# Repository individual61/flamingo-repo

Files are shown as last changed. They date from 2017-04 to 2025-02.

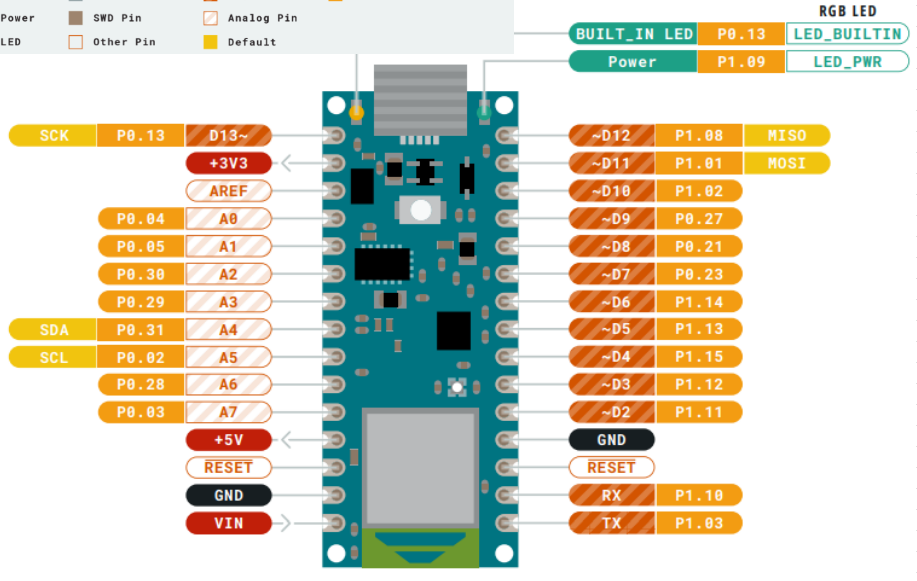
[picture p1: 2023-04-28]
Boards/Nano 33 BLE Flamingo/Flamingo Nano 33 BLE Rev 2/Arduino Nano 33 BLE Pinout.png

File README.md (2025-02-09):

FLAMINGO!

My festival buddy.My fave programs are the damped harmonic oscillator, the bouncing ball, and green fire. 

First iteration was a perfboard mess, second was a custom PCBA I designed and assembled. Currently runs off a small, flat USB power bank.



930DD853-4906-4F26-BFC8-F6EFBABEAD89

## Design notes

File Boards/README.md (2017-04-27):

This directory contains the board files.

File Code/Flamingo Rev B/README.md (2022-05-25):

Derived from the original version of Flamingo as presented at LiB 2015, then updated in 2017.

Runs on original, through-hole Flamingo hardware.

Hardware:

- Adafruit Pro Trinket 5 V
- Battery Backpack
- ADXL345/GY-291
- Adafruit APA102C pins.
- Qty 2 buttons

Setup guide, because I always forget. 

***Connections

I connect an Adafruit FTDI Fried, or CP2104 (discontinued) to the FTDI header of the Pro Trinket. I forget why I preferred this but I think it's better than uploading via USB. I USB might require unplugging and re-plugging but I'm not sure. 

I use a sparse APA102C strip for testing, at least initially. Not sure if my USB port can handle the current draw. I also have my power supply to power the light strip directly.

The grounds in this setup are linked at the light strip itself, which means that as long as the APA102C ground connects to USB ground on the Pro Trinket, they are linked. I'm pretty sure this is the case. 

WHen the light strip is powered this way, the Arduino is always powered on. 

Starting the serial monitor resets the Arduino.

***

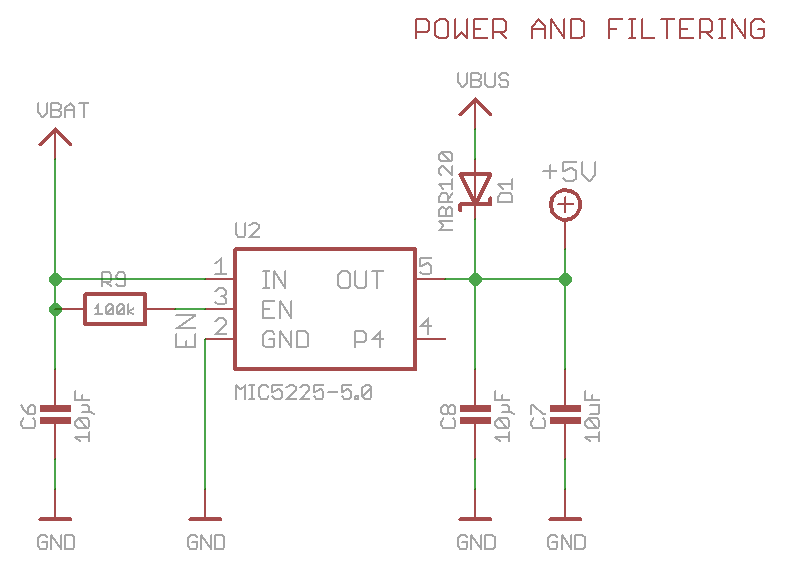
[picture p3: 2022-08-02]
Boards/Bike Flamingo IB-5V-USB/Bike Flamingo IB-5V-USB Rev 2/Images/ItsyBitsyPower.png

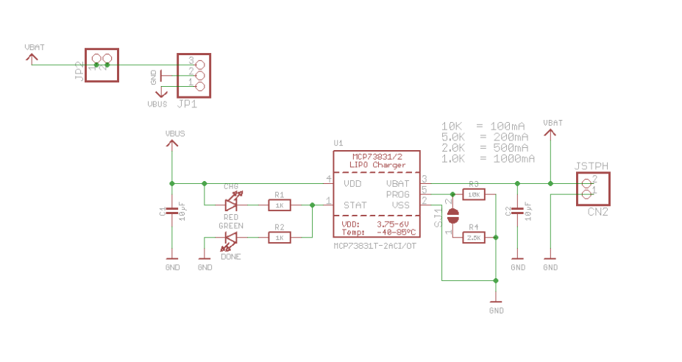
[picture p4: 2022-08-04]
Boards/Bike Flamingo IB-5V-USB/Bike Flamingo IB-5V-USB Rev 2/Images/Battery Backpack power.png

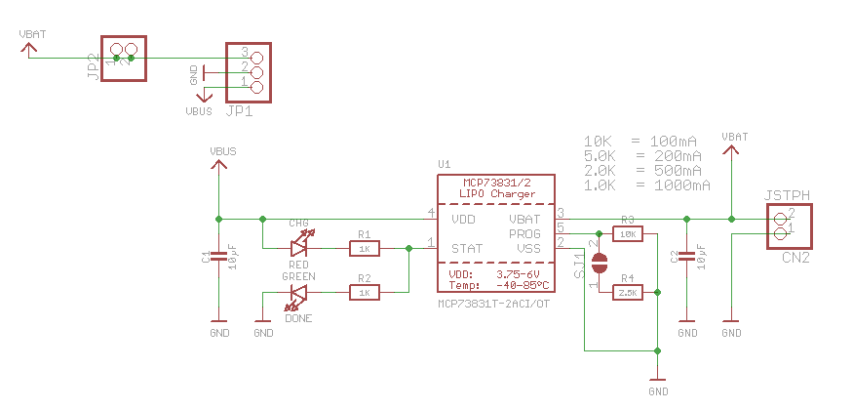
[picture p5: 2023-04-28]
Boards/Nano 33 BLE Flamingo/Flamingo Nano 33 BLE Rev 2/Adafruit Battery Backpack.png

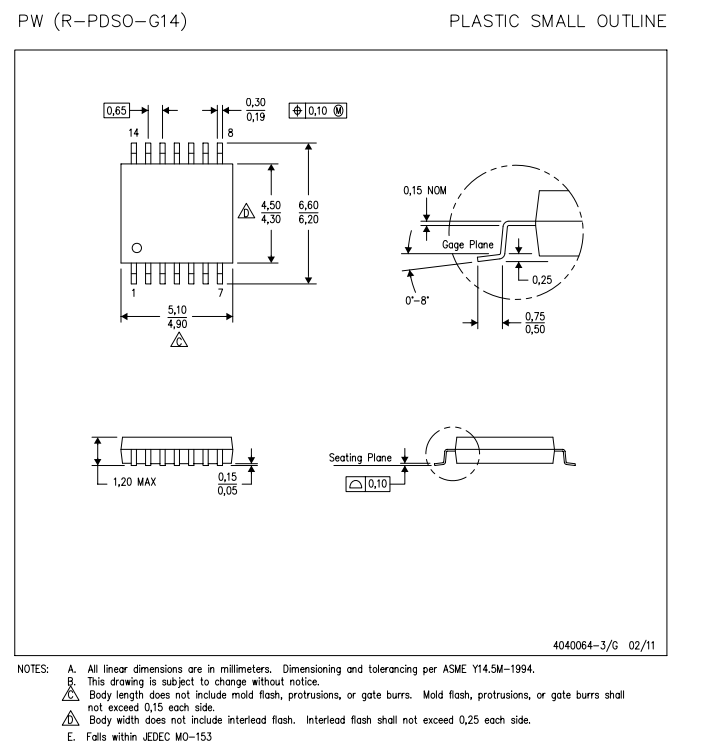
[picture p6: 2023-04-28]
Boards/Nano 33 BLE Flamingo/Flamingo Nano 33 BLE Rev 2/TSSOP 4.4 Package.png

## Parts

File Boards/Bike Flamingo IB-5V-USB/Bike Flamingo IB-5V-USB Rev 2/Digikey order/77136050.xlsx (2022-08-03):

Index | Quantity | Part Number | Manufacturer Part Number | Description | Customer Reference | Backorder | Unit Price | Extended Price
1 | 5 | 515PB-ND | 40-3979-00 | SWITCH PUSHBUTTON SPST 2A 14V |  | 0 | 2.69 | $13.45
2 | 20 | 455-1719-ND | S2B-PH-K-S(LF)(SN) | CONN HEADER R/A 2POS 2MM |  | 0 | 0.134 | $0.00
3 | 100 | CR0603-FX-3300ELFCT-ND | CR0603-FX-3300ELF | RES SMD 330 OHM 1% 1/10W 0603 |  | 0 | 0.0068 | $0.68
4 | 10 | A98335-ND | 282834-4 | TERM BLK 4P SIDE ENT 2.54MM PCB |  | 0 | 2.515 | $25.15
5 | 100 | CR0603-FX-4701ELFCT-ND | CR0603-FX-4701ELF | RES SMD 4.7K OHM 1% 1/10W 0603 |  | 0 | 0.0065 | $0.65
6 | 6 | 478-12972-1-ND | TPSF107M016R0200 | CAP TANT 100UF 20% 16V 2312 |  | 0 | 1.85 | $11.10
 |  |  |  |  |  |  | Subtotal | $51.03

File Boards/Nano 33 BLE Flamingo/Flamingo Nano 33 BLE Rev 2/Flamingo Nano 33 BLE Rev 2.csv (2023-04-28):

Source: | D:\Google Drive 6TB\Projects\Flamingo\flaming-repo\Boards\Nano 33 BLE Flamingo\Flamingo Nano 33 BLE Rev 2\Flamingo Nano 33 BLE Rev 2.kicad_sch
Date: | 4/26/2023 11:23:23 AM
Tool: | Eeschema 7.0.2
Generator: | D:\Program Files 6TB\KiCAD\7.0\bin\scripting\plugins/bom_csv_grouped_by_value_with_fp.py
Component Count: | 11
Ref | Qnty | Value | Cmp name | Footprint | Description | Vendor | DNP
C1 | 1 | 10 uF | C_Small_vert | Capacitor_SMD:C_0805_2012Metric_Pad1.18x1.45mm_HandSolder | Unpolarized capacitor vertical
C2 | 1 | 100uF | CP1_Small_vert | MyCapacitors:Cap Tant 100uF 16V 2mm height F size Kyocera AVX TPSF107M016R0200 | Polarised capacitor vertical
J1 | 1 | Button Board Term | Screw_Terminal_01x04 TE 282834-4 | TerminalBlock_TE-Connectivity:TerminalBlock_TE_282834-4_1x04_P2.54mm_Horizontal | Generic screw terminal, single row, 01x04, script generated (kicad-library-utils/schlib/autogen/connector/)
J2 | 1 | APA102C | Screw_Terminal_01x04 TE 282834-4 | TerminalBlock_TE-Connectivity:TerminalBlock_TE_282834-4_1x04_P2.54mm_Horizontal | Generic screw terminal, single row, 01x04, script generated (kicad-library-utils/schlib/autogen/connector/)
R1, R2, R3 | 3 | 4.7k | R_vert | Resistor_SMD:R_0603_1608Metric_Pad0.98x0.95mm_HandSolder | Resistor Vertical
R4, R5 | 2 | 330 | R_horiz_1 | Resistor_SMD:R_0603_1608Metric_Pad0.98x0.95mm_HandSolder | Resistor Horizontal
U1 | 1 | SN74AHCT125QPWRQ1 | 74AHCT125_Quad_Buffer-Level_Shifter | Package_SO:TSSOP-14_4.4x5mm_P0.65mm
XA1 | 1 | Arduino_Nano_33_BLE_Socket | Arduino_Nano_33_BLE_Socket | PCM_arduino-library:Arduino_Nano_Every_Socket | Socket for Arduino Nano 33 BLE

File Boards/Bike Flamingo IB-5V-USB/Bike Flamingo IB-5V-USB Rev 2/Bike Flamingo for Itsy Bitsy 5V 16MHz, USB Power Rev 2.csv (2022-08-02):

Source: | G:\My Drive\Projects\Flamingo\flaming-repo\Boards\Bike Flamingo for Itsy Bitsy 5V 16MHz, USB Power\Bike Flamingo for Itsy Bitsy 5V 16MHz, USB Power Rev 1\Bike Flamingo for Itsy Bitsy 5V 16MHz, USB Power Rev 1.kicad_sch
Date: | 8/2/2022 11:48:54 AM
Tool: | Eeschema (6.0.7)
Generator: | C:\Program Files\KiCad\6.0\bin\scripting\plugins/bom_csv_grouped_by_value_with_fp.py
Component Count: | 10
Ref | Qnty | Value | Cmp name | Footprint | Description | Vendor
C1, | 1 | 100uF | CP1_Small_vert | Capacitor_Tantalum_SMD:CP_EIA-6032-28_Kemet-C_Pad2.25x2.35mm_HandSolder | Polarised capacitor vertical
J1, | 1 | Battery Connector | 01x02_Connector | Connector_JST:JST_PH_S2B-PH-K_1x02_P2.00mm_Horizontal | Generic connector, single row, 01x02
J2, J3, | 2 | Button Board Terminal | Screw_Terminal_01x04 | TerminalBlock_TE-Connectivity:TerminalBlock_TE_282834-4_1x04_P2.54mm_Horizontal | Generic screw terminal, single row, 01x04, script generated (kicad-library-utils/schlib/autogen/connector/)
R1, R2, R3, | 3 | 4.7k | R_vert | Resistor_SMD:R_0603_1608Metric_Pad0.98x0.95mm_HandSolder | Resistor Vertical
R4, R5, | 2 | 330 | R_horiz | Resistor_SMD:R_0603_1608Metric_Pad0.98x0.95mm_HandSolder | Resistor Horizontal
U1, | 1 | Adafruit_ItsyBitsy_5V_16MHz | Adafruit_ItsyBitsy_5V_16MHz | MyBoards:Adafruit Itsy Bitsy 5V 16 MHz

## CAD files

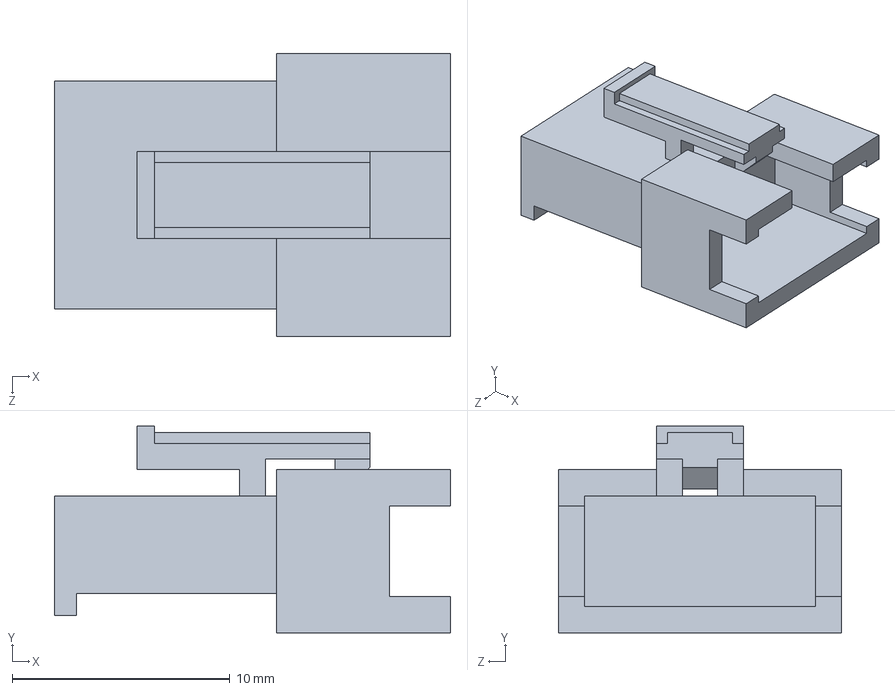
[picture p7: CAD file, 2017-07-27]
Boards/Flamingo PCBA/Components/JST SM Connectors/SMR-04V-B.STEP
18.2 x 9.50 x 13.0 mm

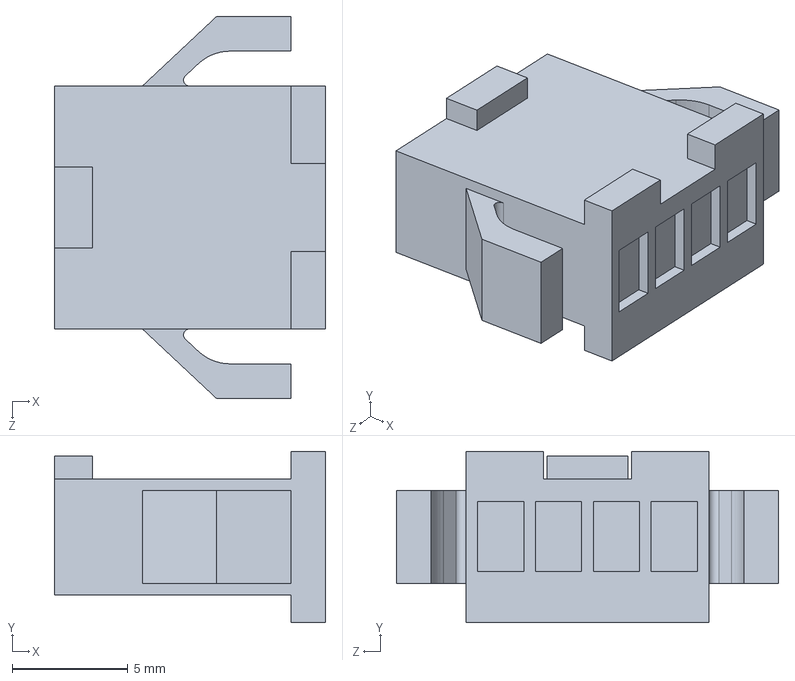
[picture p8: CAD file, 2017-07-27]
Boards/Flamingo PCBA/Components/JST SM Connectors/SMP-04V-BC.STEP
11.7 x 7.40 x 16.5 mm

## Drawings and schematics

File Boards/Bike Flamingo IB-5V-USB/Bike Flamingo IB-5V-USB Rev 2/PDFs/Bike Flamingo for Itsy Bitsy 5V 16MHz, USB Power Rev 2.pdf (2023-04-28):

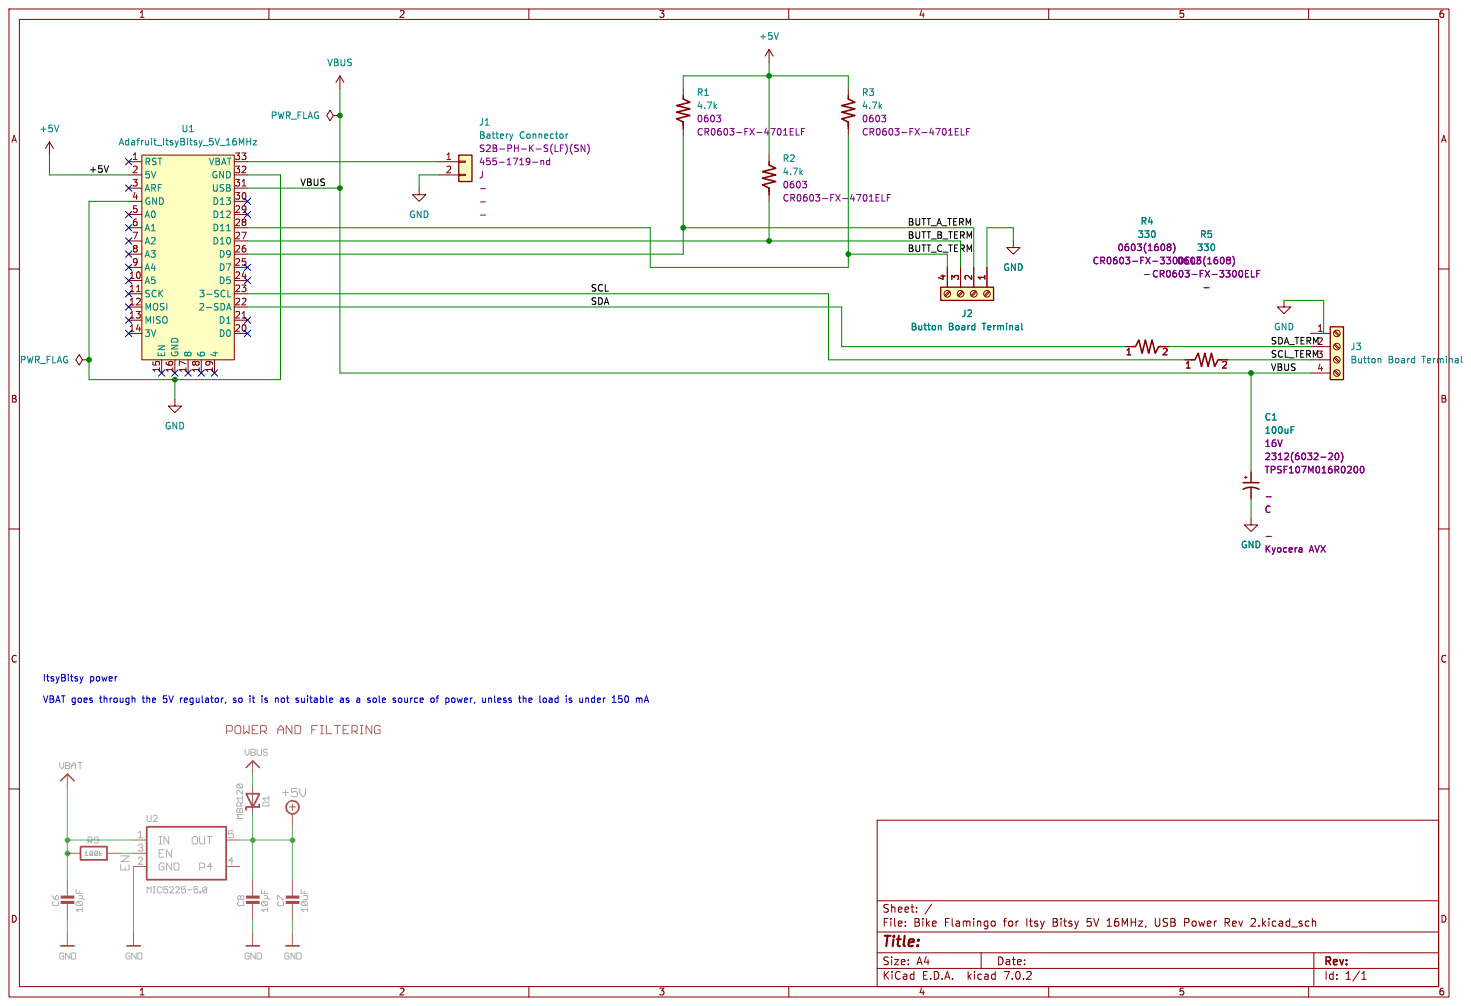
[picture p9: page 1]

J1Battery Connector S2B-PH-K-S(LF)(SN) 455-1719-nd

-Kyocera AVX GND GND

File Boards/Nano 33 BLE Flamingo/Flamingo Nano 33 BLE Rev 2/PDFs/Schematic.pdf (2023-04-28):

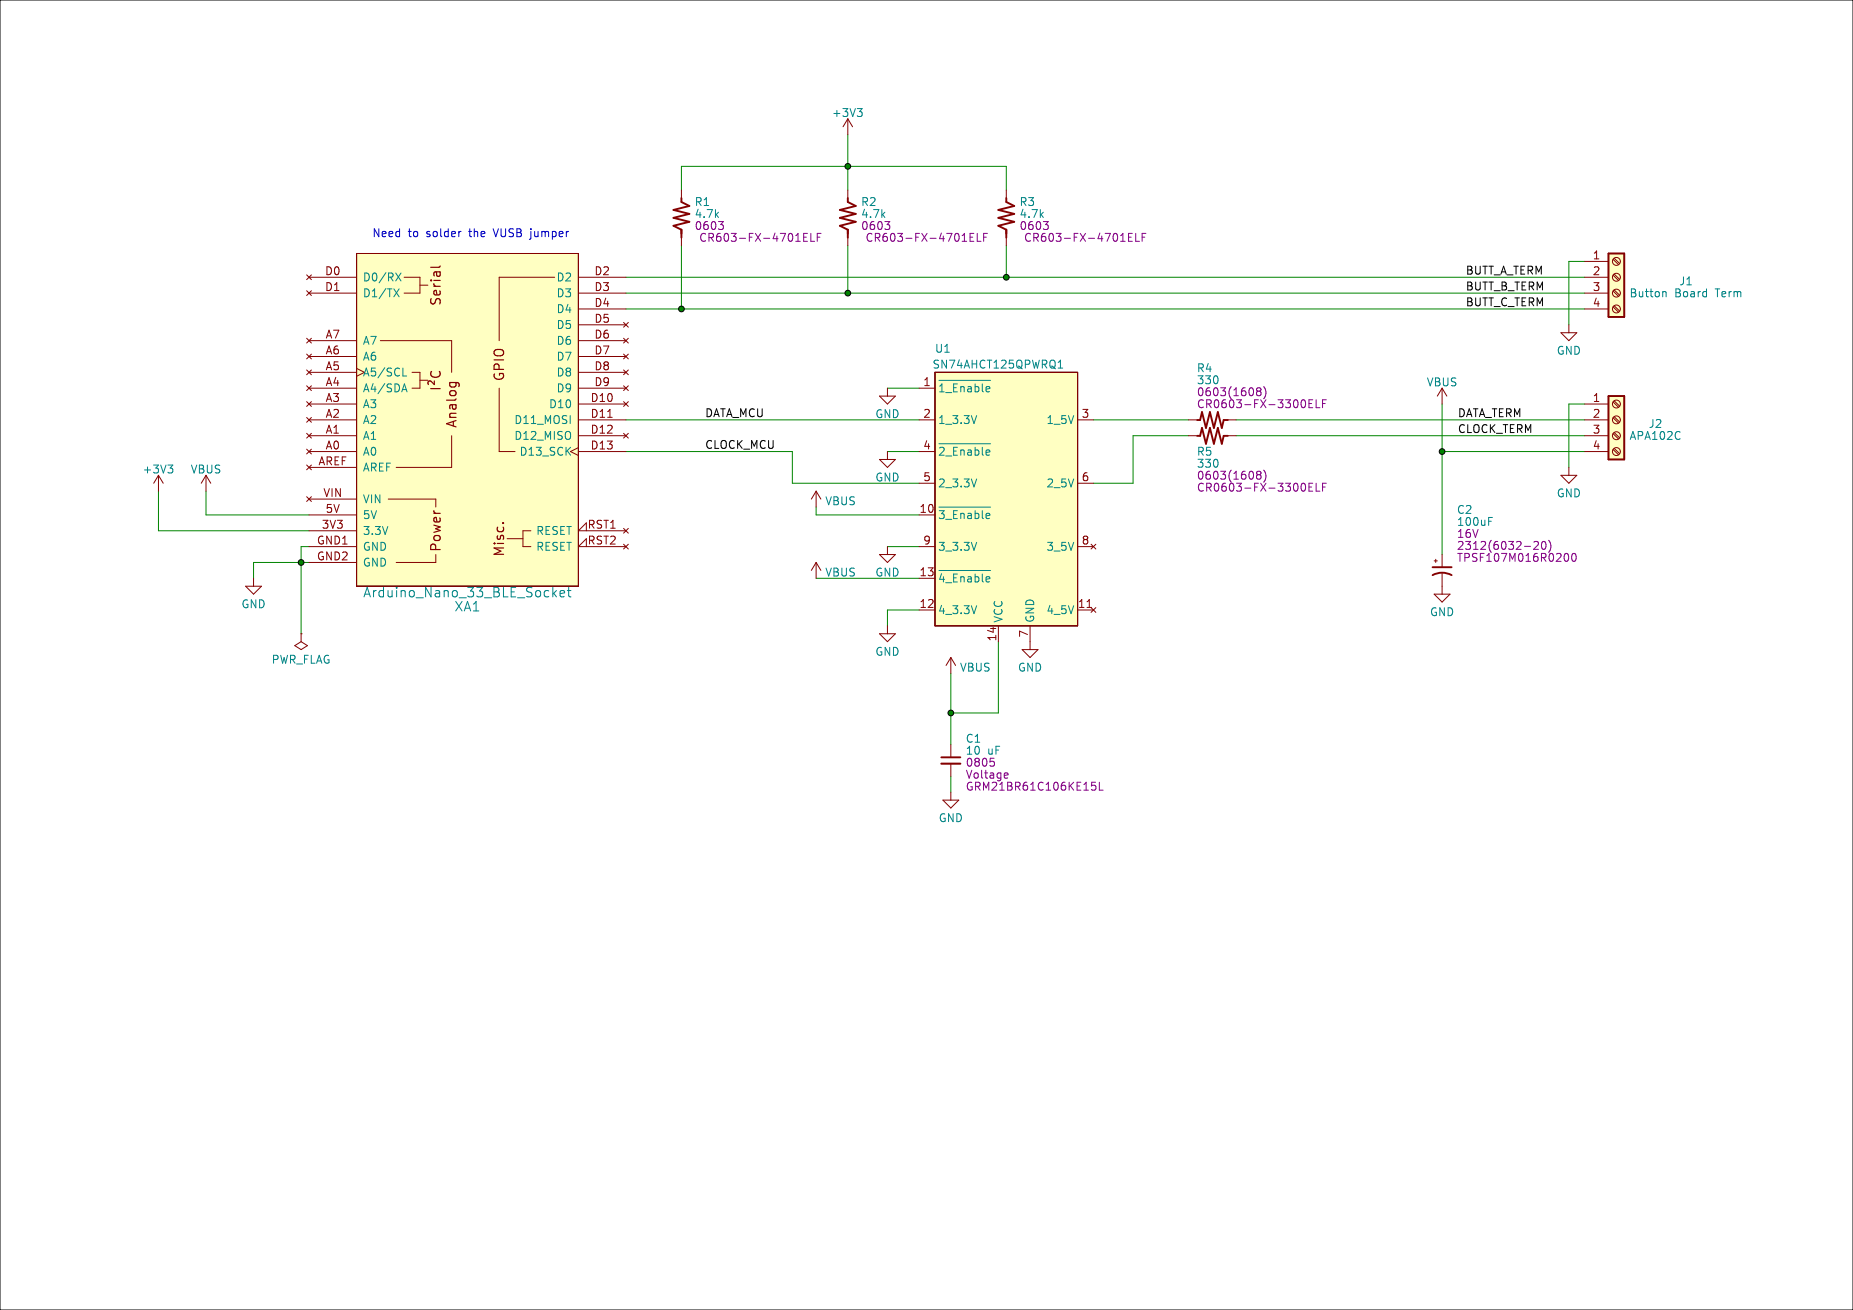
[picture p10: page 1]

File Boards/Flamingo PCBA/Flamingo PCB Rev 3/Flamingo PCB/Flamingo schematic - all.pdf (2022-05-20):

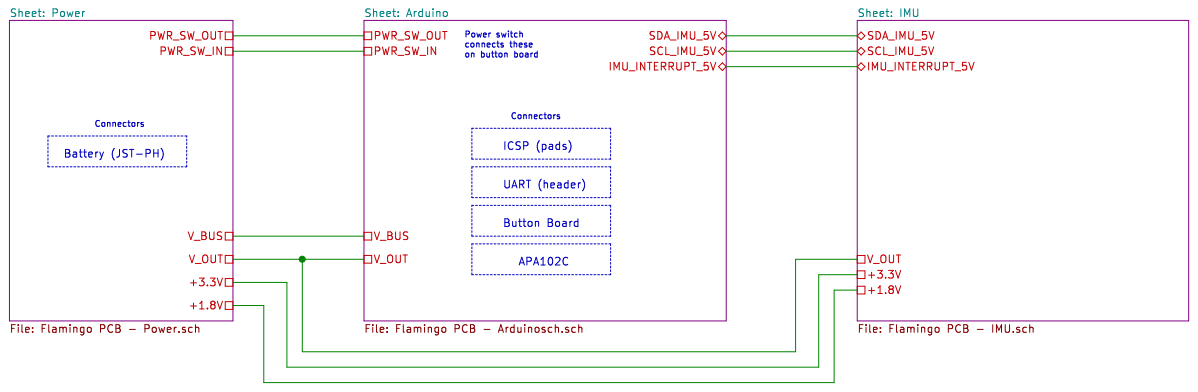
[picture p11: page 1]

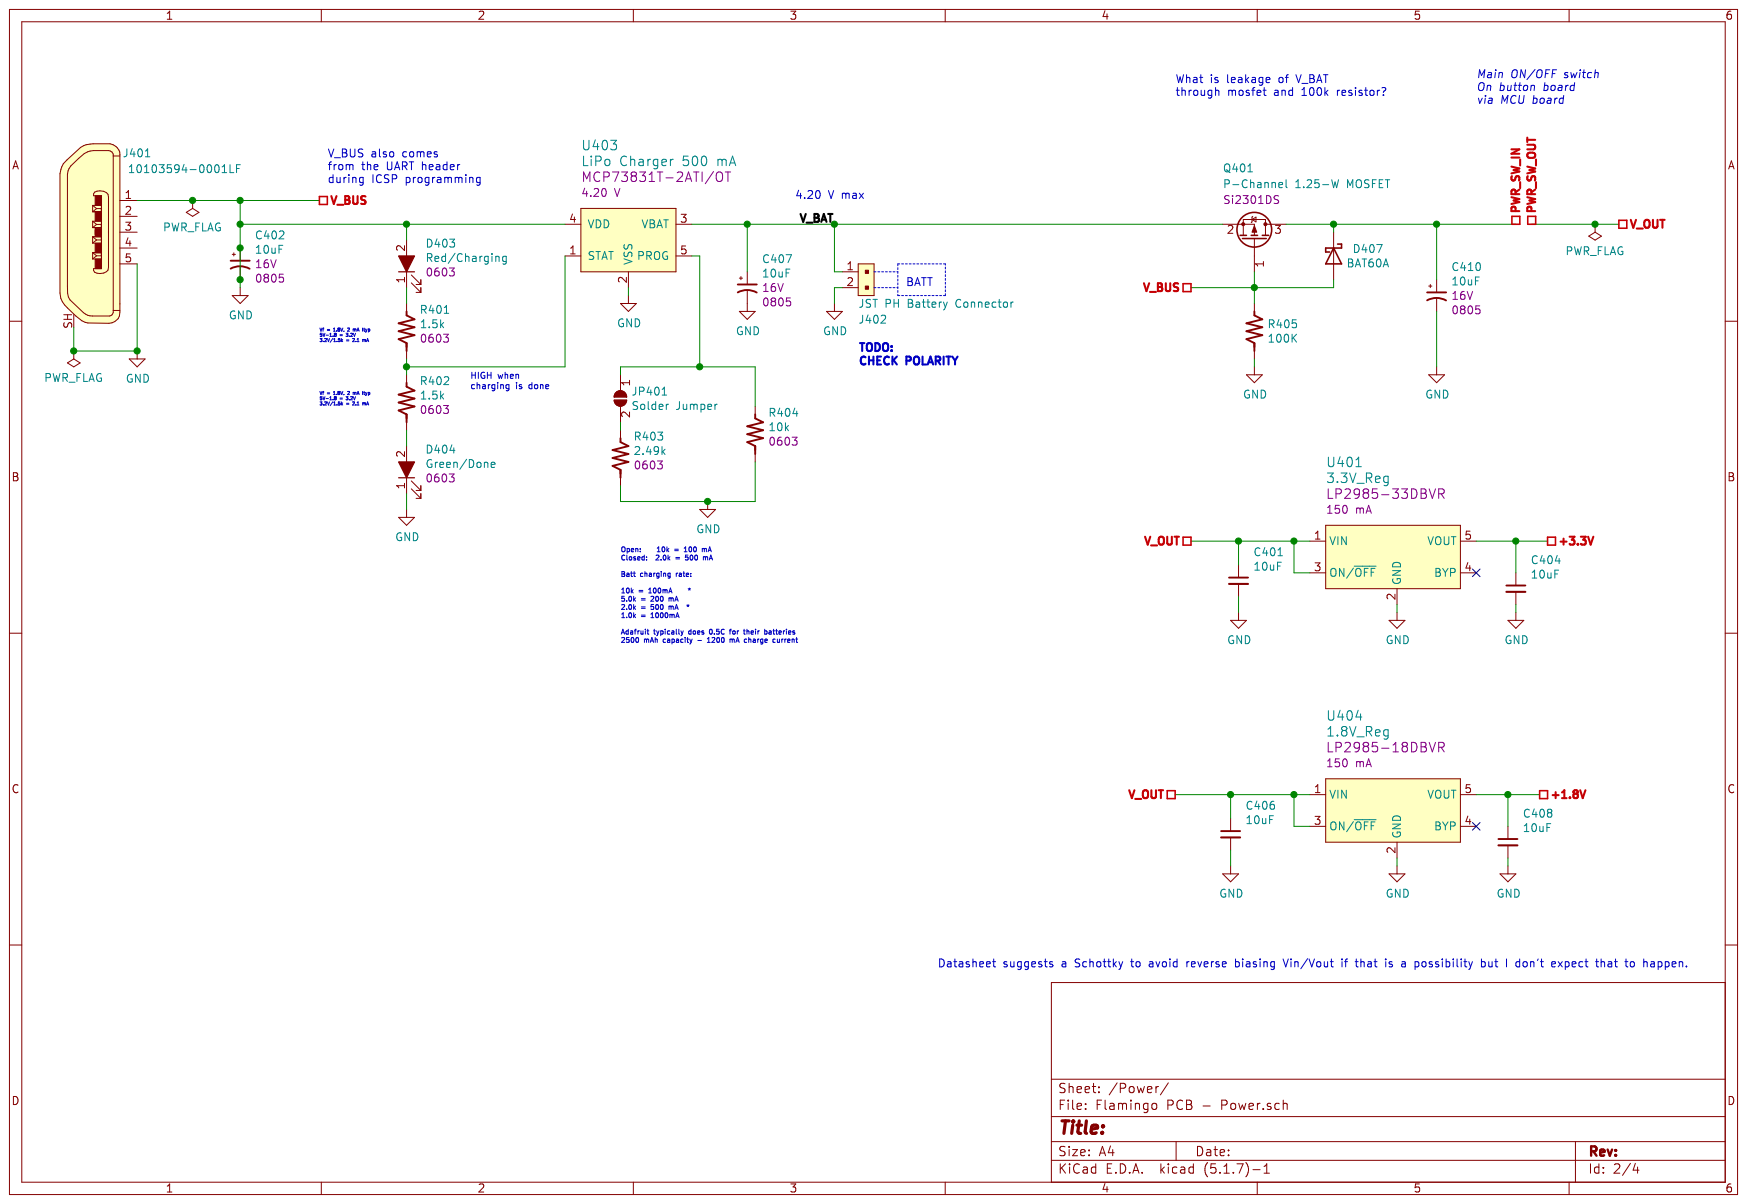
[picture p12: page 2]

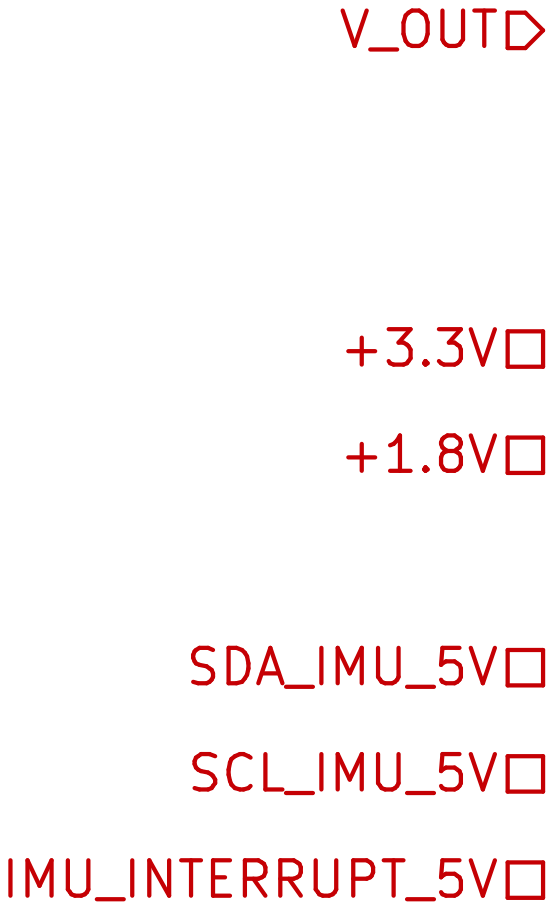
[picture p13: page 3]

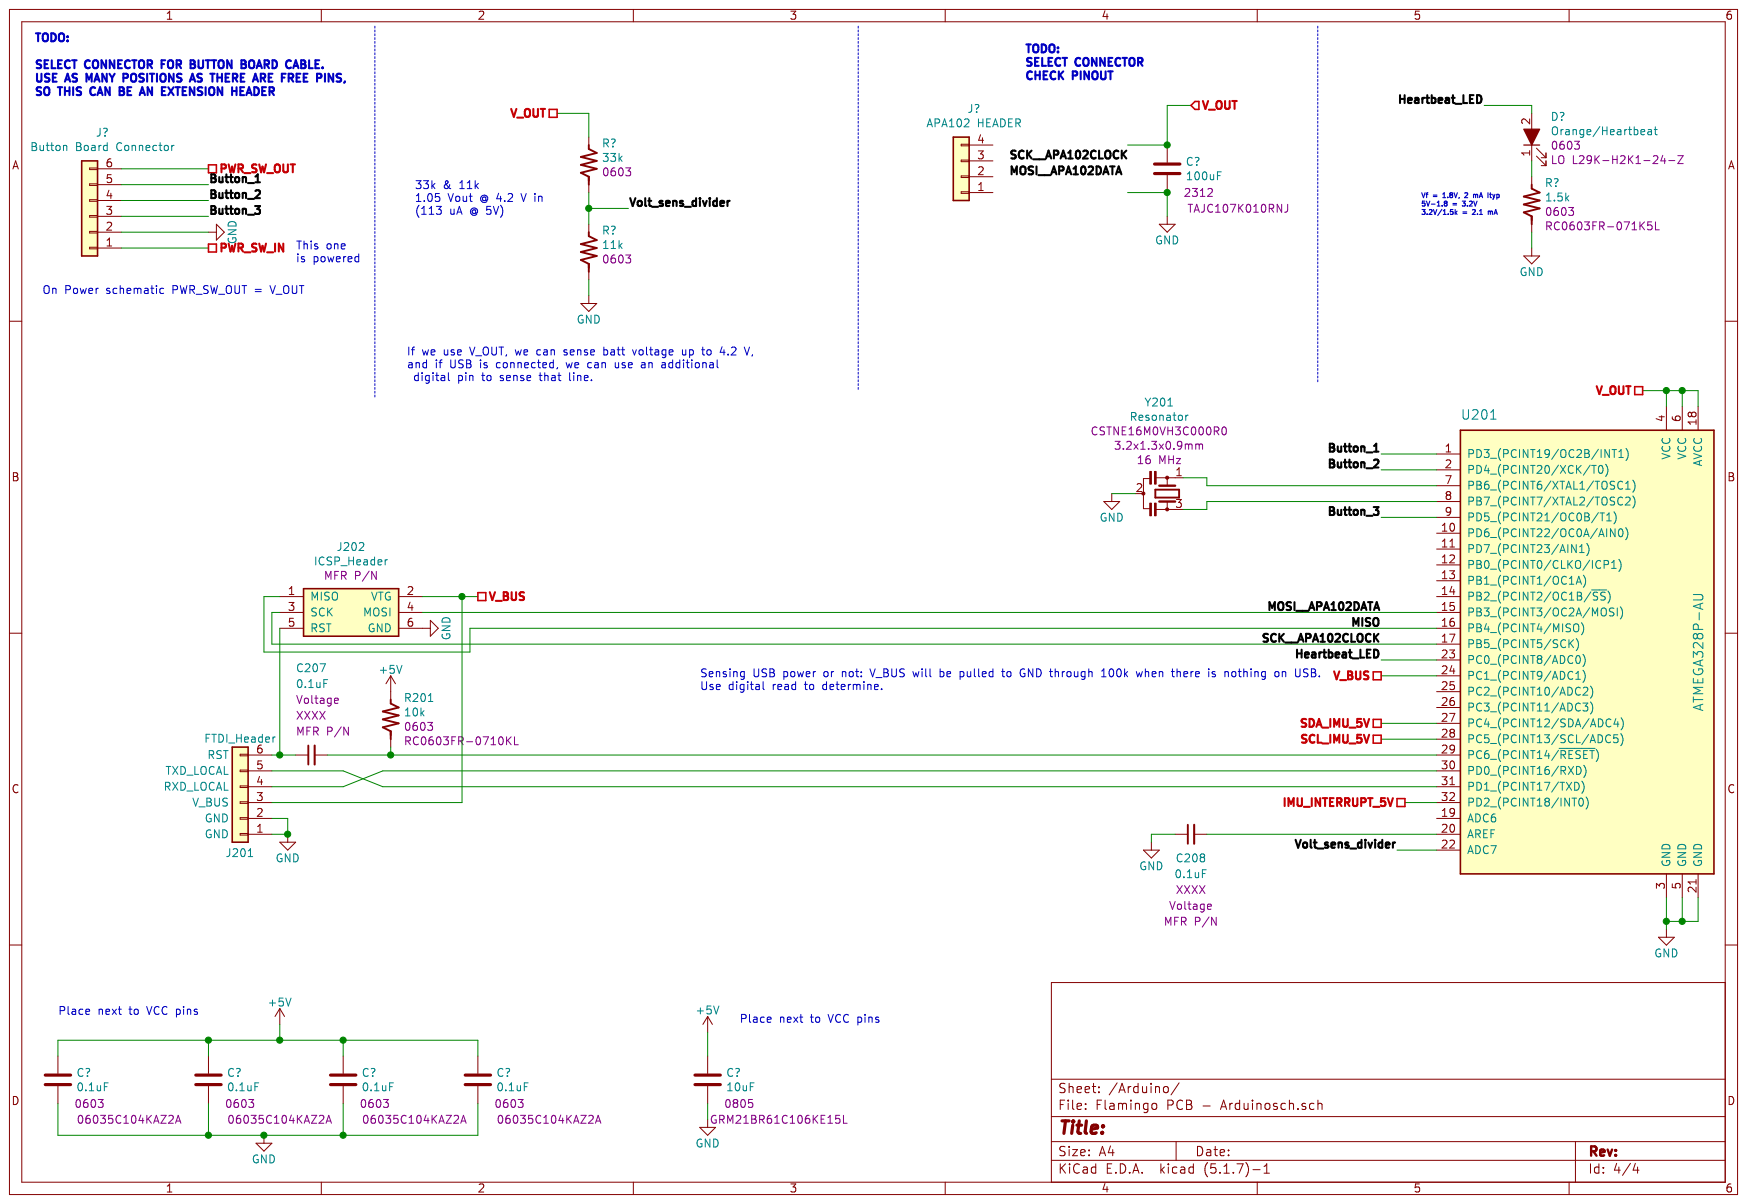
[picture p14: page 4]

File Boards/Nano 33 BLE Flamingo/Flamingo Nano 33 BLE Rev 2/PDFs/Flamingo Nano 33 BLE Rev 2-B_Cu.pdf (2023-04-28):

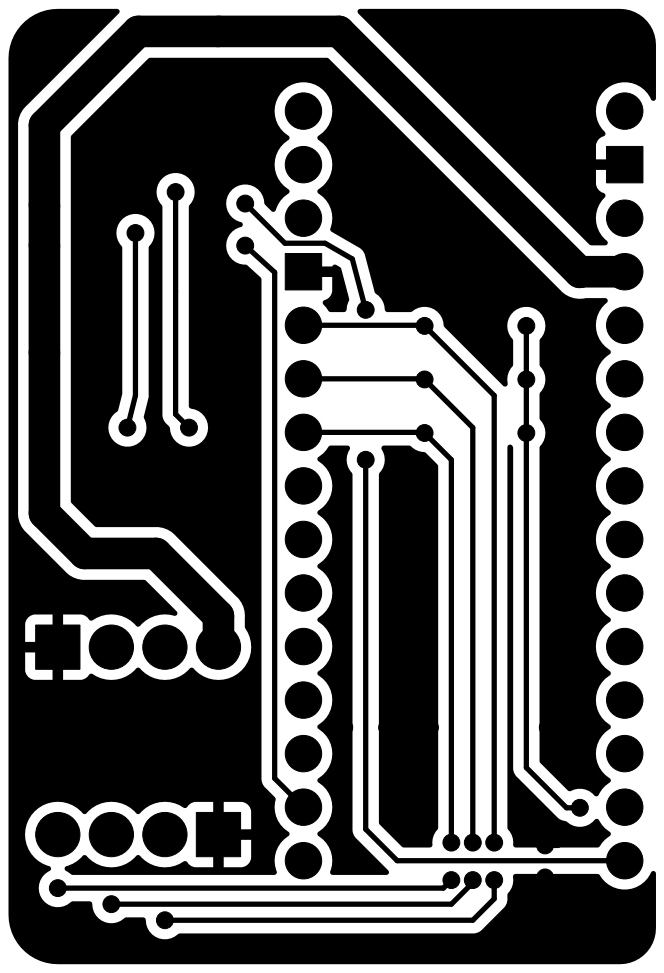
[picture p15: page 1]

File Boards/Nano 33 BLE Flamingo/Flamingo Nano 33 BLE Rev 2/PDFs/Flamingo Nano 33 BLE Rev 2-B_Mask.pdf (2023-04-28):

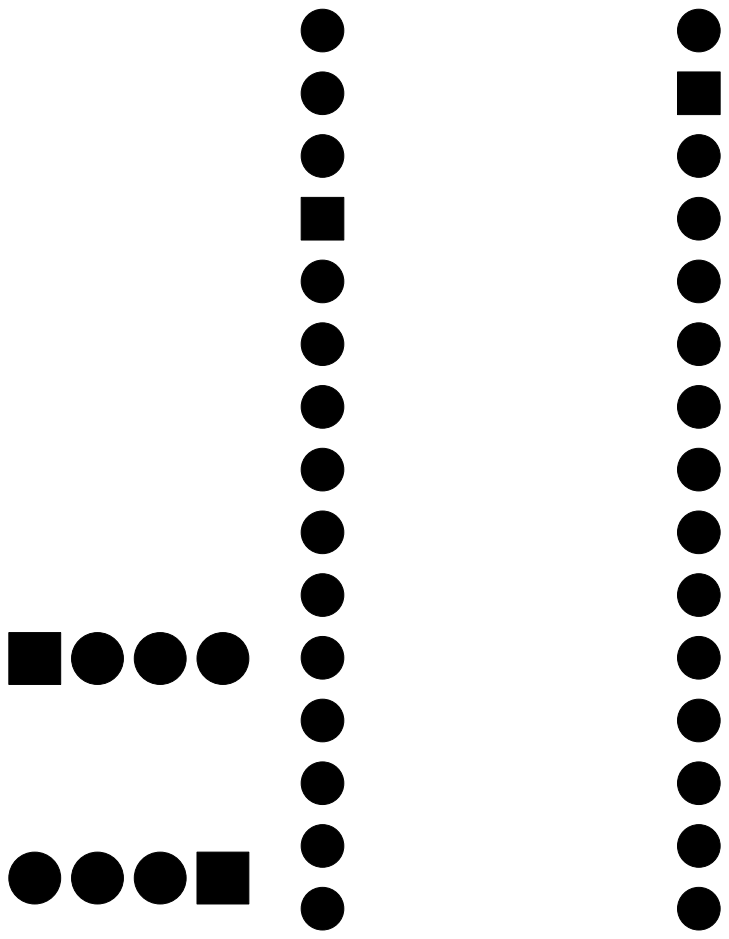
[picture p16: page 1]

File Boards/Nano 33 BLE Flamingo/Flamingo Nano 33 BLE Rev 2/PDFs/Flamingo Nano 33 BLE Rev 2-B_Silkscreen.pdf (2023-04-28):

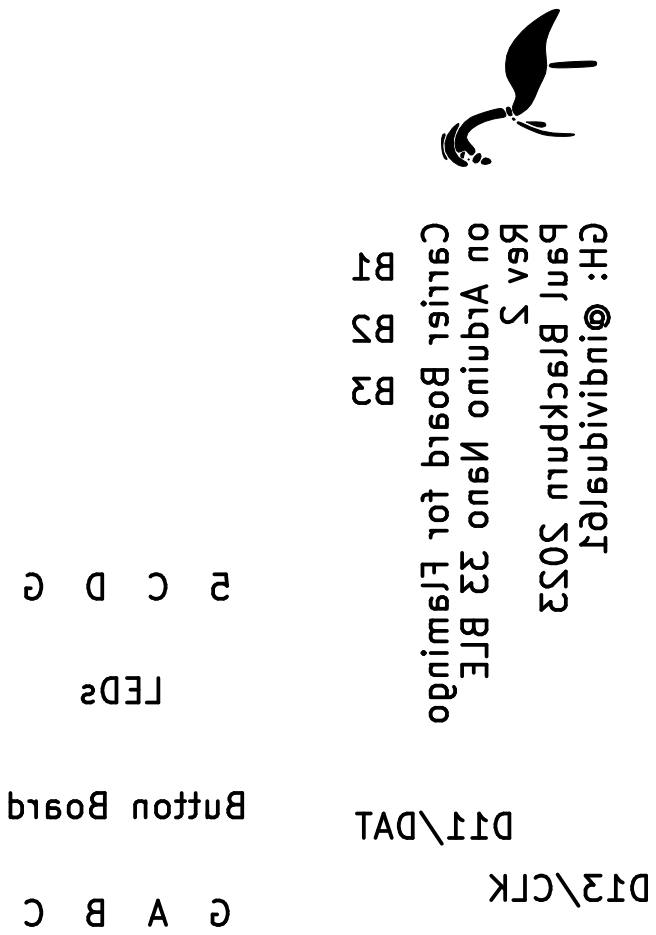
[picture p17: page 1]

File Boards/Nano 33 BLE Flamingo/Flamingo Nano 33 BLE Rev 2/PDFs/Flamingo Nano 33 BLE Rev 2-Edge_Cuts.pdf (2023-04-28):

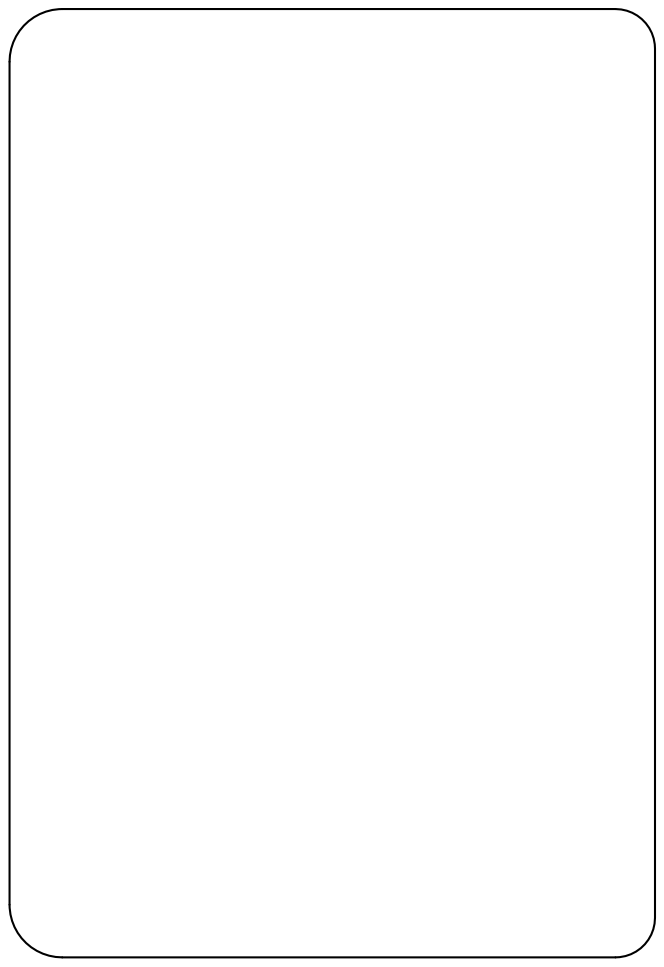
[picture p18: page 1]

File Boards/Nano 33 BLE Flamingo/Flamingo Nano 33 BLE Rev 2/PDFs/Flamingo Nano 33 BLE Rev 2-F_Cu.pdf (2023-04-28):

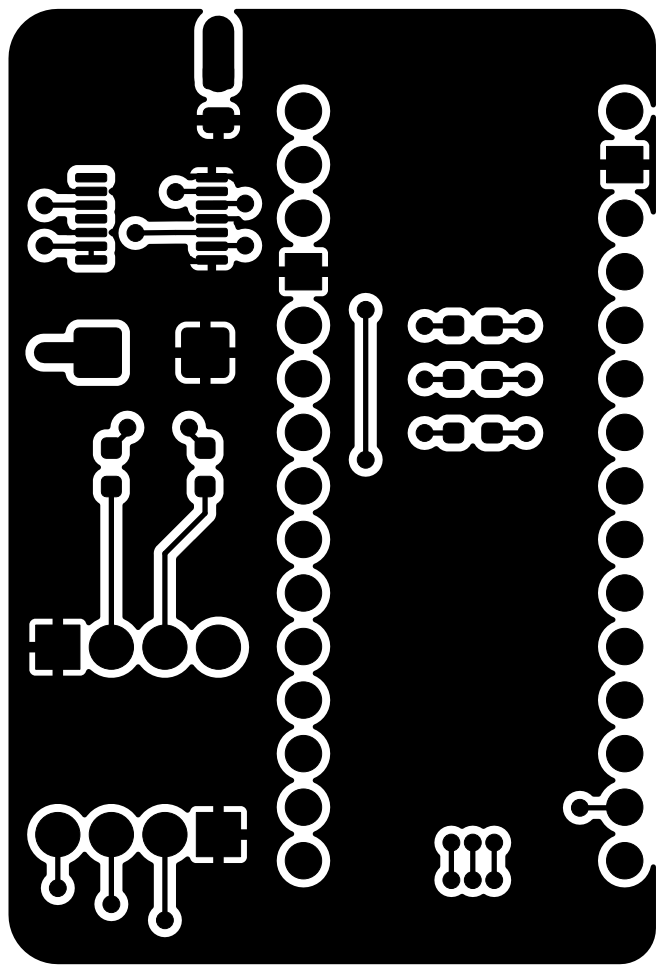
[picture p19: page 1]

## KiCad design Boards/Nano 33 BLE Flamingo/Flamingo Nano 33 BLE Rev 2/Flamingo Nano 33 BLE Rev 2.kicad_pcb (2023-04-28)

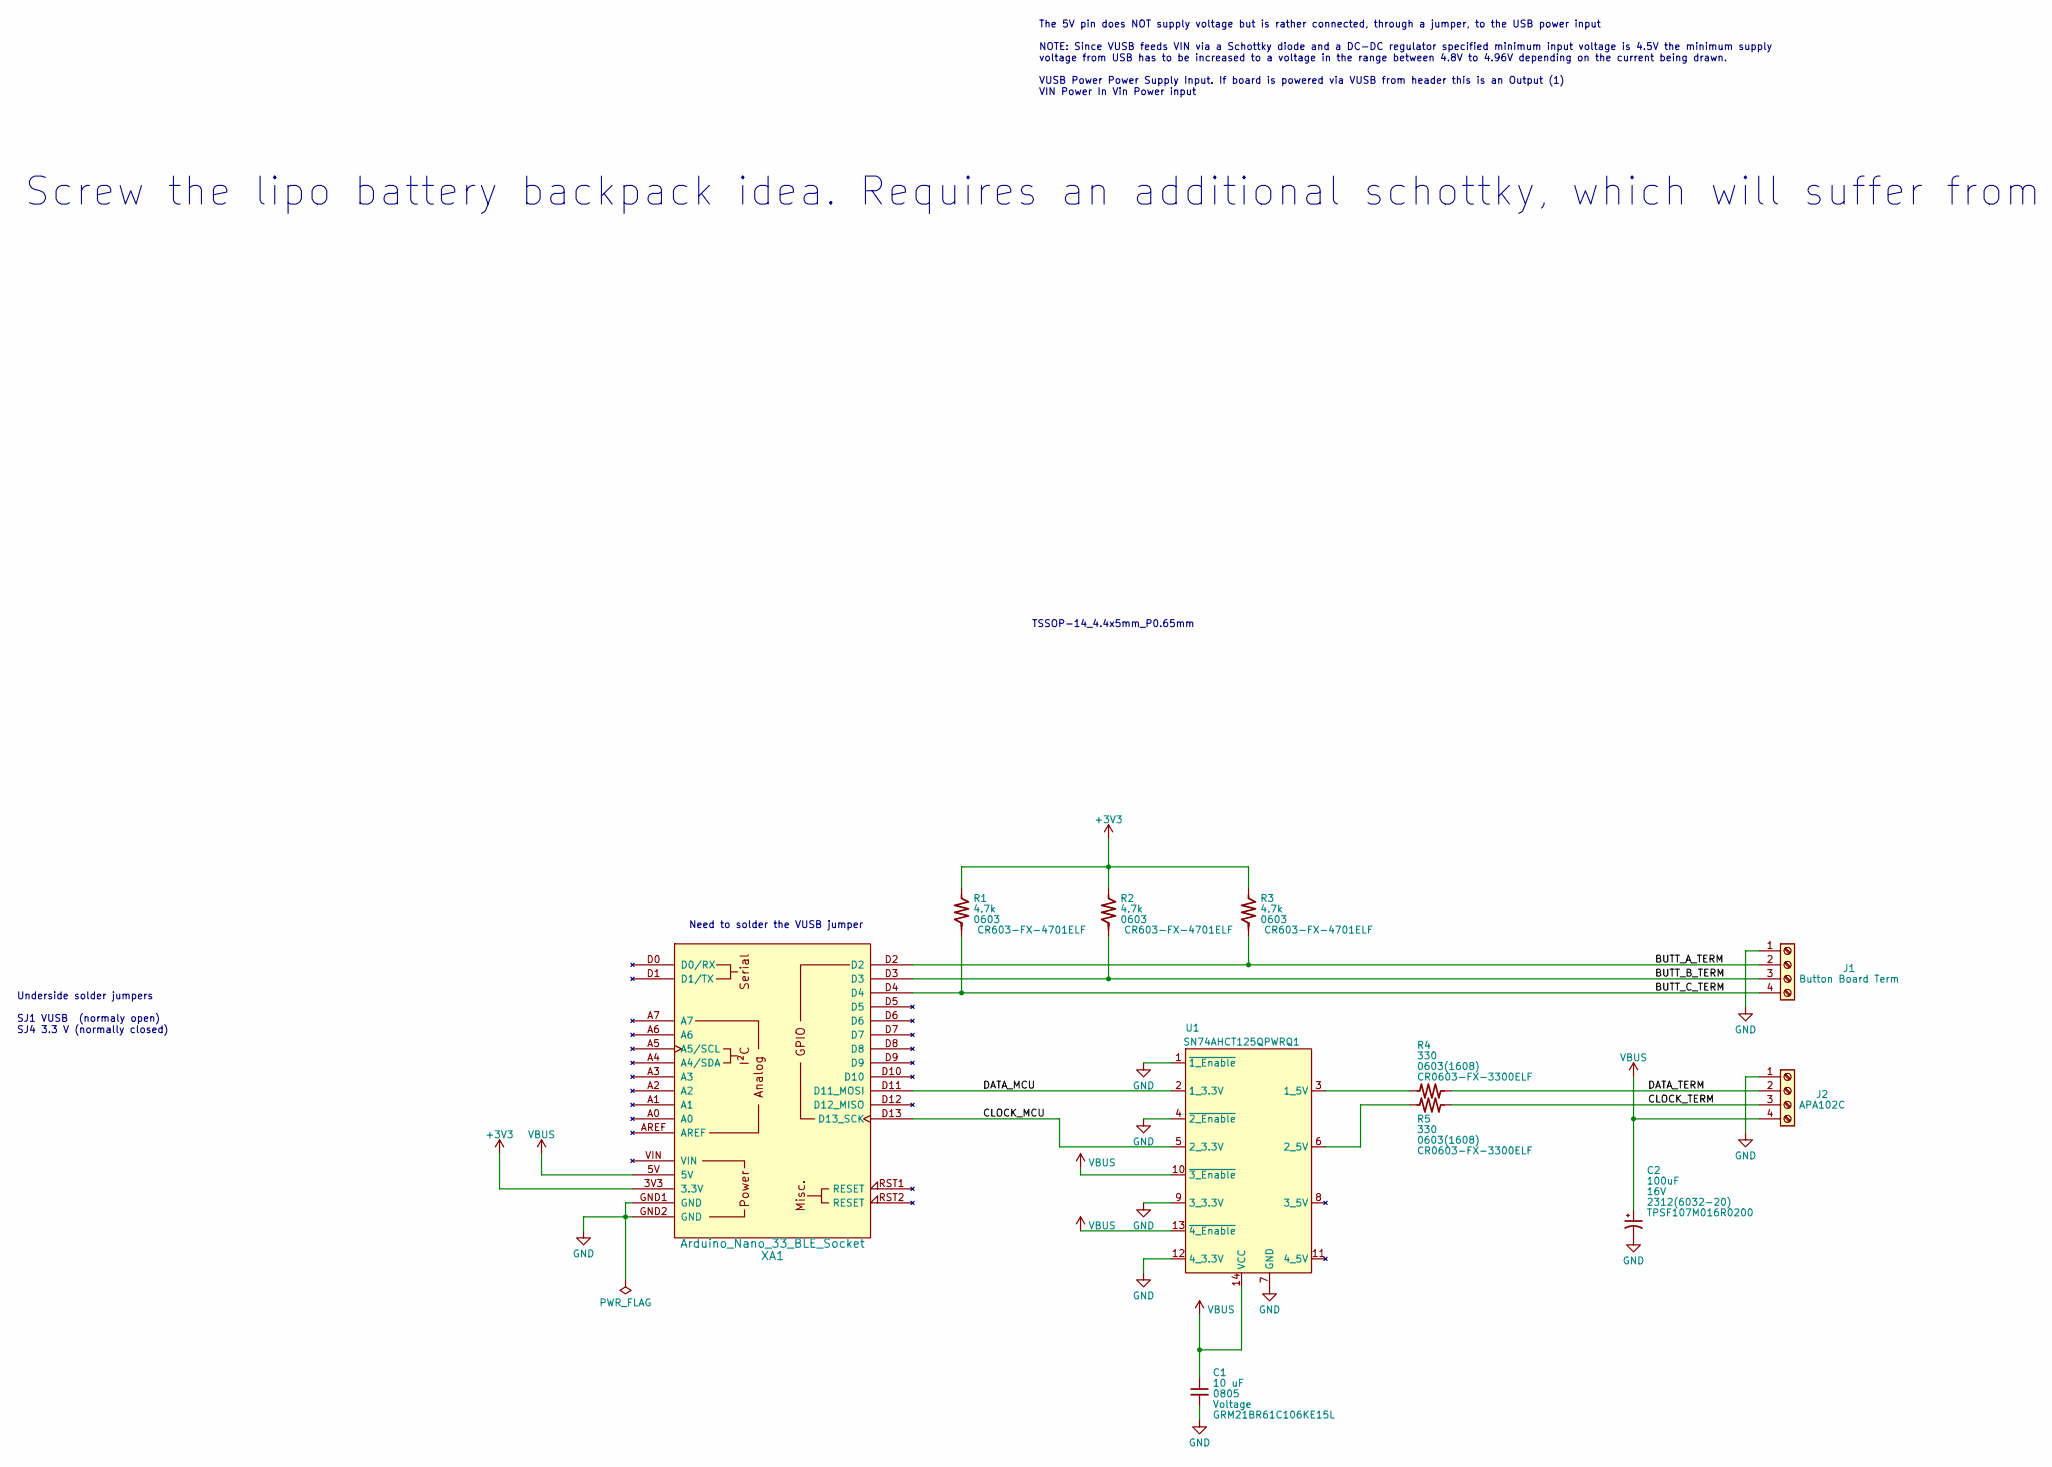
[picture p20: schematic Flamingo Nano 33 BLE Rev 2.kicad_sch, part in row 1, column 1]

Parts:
C1: 10 uF; C_0805_2012Metric_Pad1.18x1.45mm_HandSolder; Voltage Rating Voltage; MPN GRM21BR61C106KE15L
C2: 100uF; CP_EIA-6032-20_AVX-F_Pad2.25x2.35mm_HandSolder; Voltage Rating 16V; MFR P/N TPSF107M016R0200
J1: Button Board Term; TerminalBlock_TE_282834-4_1x04_P2.54mm_Horizontal; MFR PN 282834-4; DIGIKEY PN A98335-ND
J2: APA102C; TerminalBlock_TE_282834-4_1x04_P2.54mm_Horizontal; MFR PN 282834-4; DIGIKEY PN A98335-ND
R1, R2, R3: 4.7k; R_0603_1608Metric_Pad0.98x0.95mm_HandSolder; MPN CR603-FX-4701ELF; Digi-Key_PN 455-1719-ND
R4, R5: 330; R_0603_1608Metric_Pad0.98x0.95mm_HandSolder; MPN CR0603-FX-3300ELF
U1: SN74AHCT125QPWRQ1; TSSOP-14_4.4x5mm_P0.65mm
XA1: Arduino_Nano_33_BLE_Socket; Arduino_Nano_Every_Socket

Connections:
+3V3: R1.1, R2.1, R3.1, XA1.3V3 (3.3V)
/BUTT_A_TERM: J1.2, R3.2, XA1.D2
/BUTT_B_TERM: J1.3, R2.2, XA1.D3
/BUTT_C_TERM: J1.4, R1.2, XA1.D4
/CLOCK_MCU: U1.5 (2_3.3V), XA1.D13 (D13_SCK)
/CLOCK_TERM: J2.3, R5.2
/DATA_MCU: U1.2 (1_3.3V), XA1.D11 (D11_MOSI)
/DATA_TERM: J2.2, R4.2
GND: C1.2, C2.2, J1.1, J2.1, U1.1 (~1_Enable), U1.4 (~2_Enable), U1.7 (GND), U1.9 (3_3.3V), U1.12 (4_3.3V), XA1.GND1 (GND), XA1.GND2 (GND)
unnamed: R4.1, U1.3 (1_5V)
unnamed: R5.1, U1.6 (2_5V)
VBUS: C1.1, C2.1, J2.4, U1.10 (~3_Enable), U1.13 (~4_Enable), U1.14 (VCC), XA1.5V

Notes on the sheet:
Underside solder jumpers SJ1 VUSB (normaly open) SJ4 3.3 V (normally closed)
Screw the lipo battery backpack idea. Requires an additional schottky, which will suffer from Vf drop when running lights. Just use a USB power bank.
TSSOP-14_4.4x5mm_P0.65mm
The 5V pin does NOT supply voltage but is rather connected, through a jumper, to the USB power input NOTE: Since VUSB feeds VIN via a Schottky diode and a DC-DC regulator specified minimum input voltage is 4.5V the minimum supply voltage from USB has to be increased to a voltage in the range betwee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
Need to solder the VUSB jumper

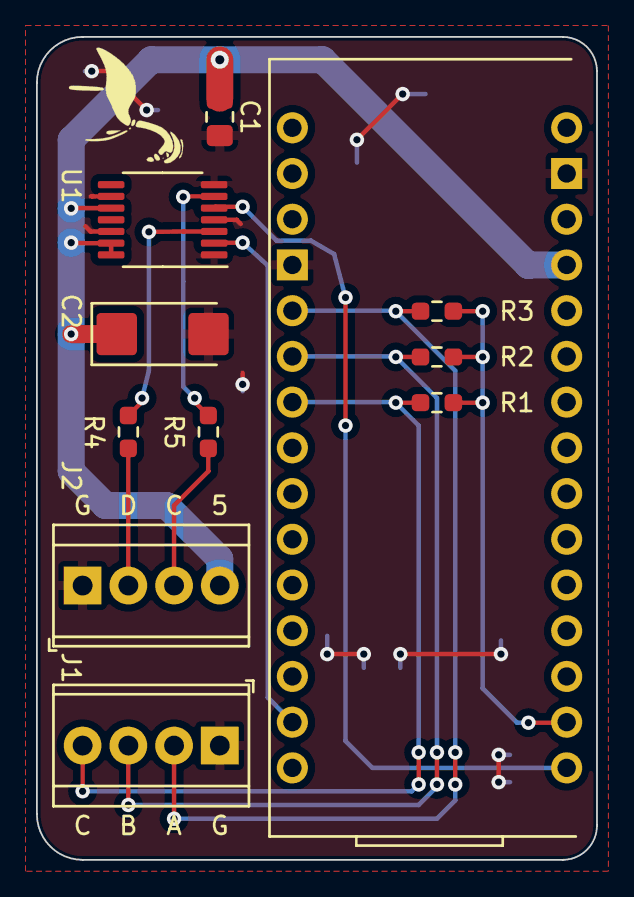
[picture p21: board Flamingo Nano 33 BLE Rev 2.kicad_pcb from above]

Board: 2 copper layers, 31.1 x 45.7 mm, 11 parts (0 on the bottom side), 12 nets.

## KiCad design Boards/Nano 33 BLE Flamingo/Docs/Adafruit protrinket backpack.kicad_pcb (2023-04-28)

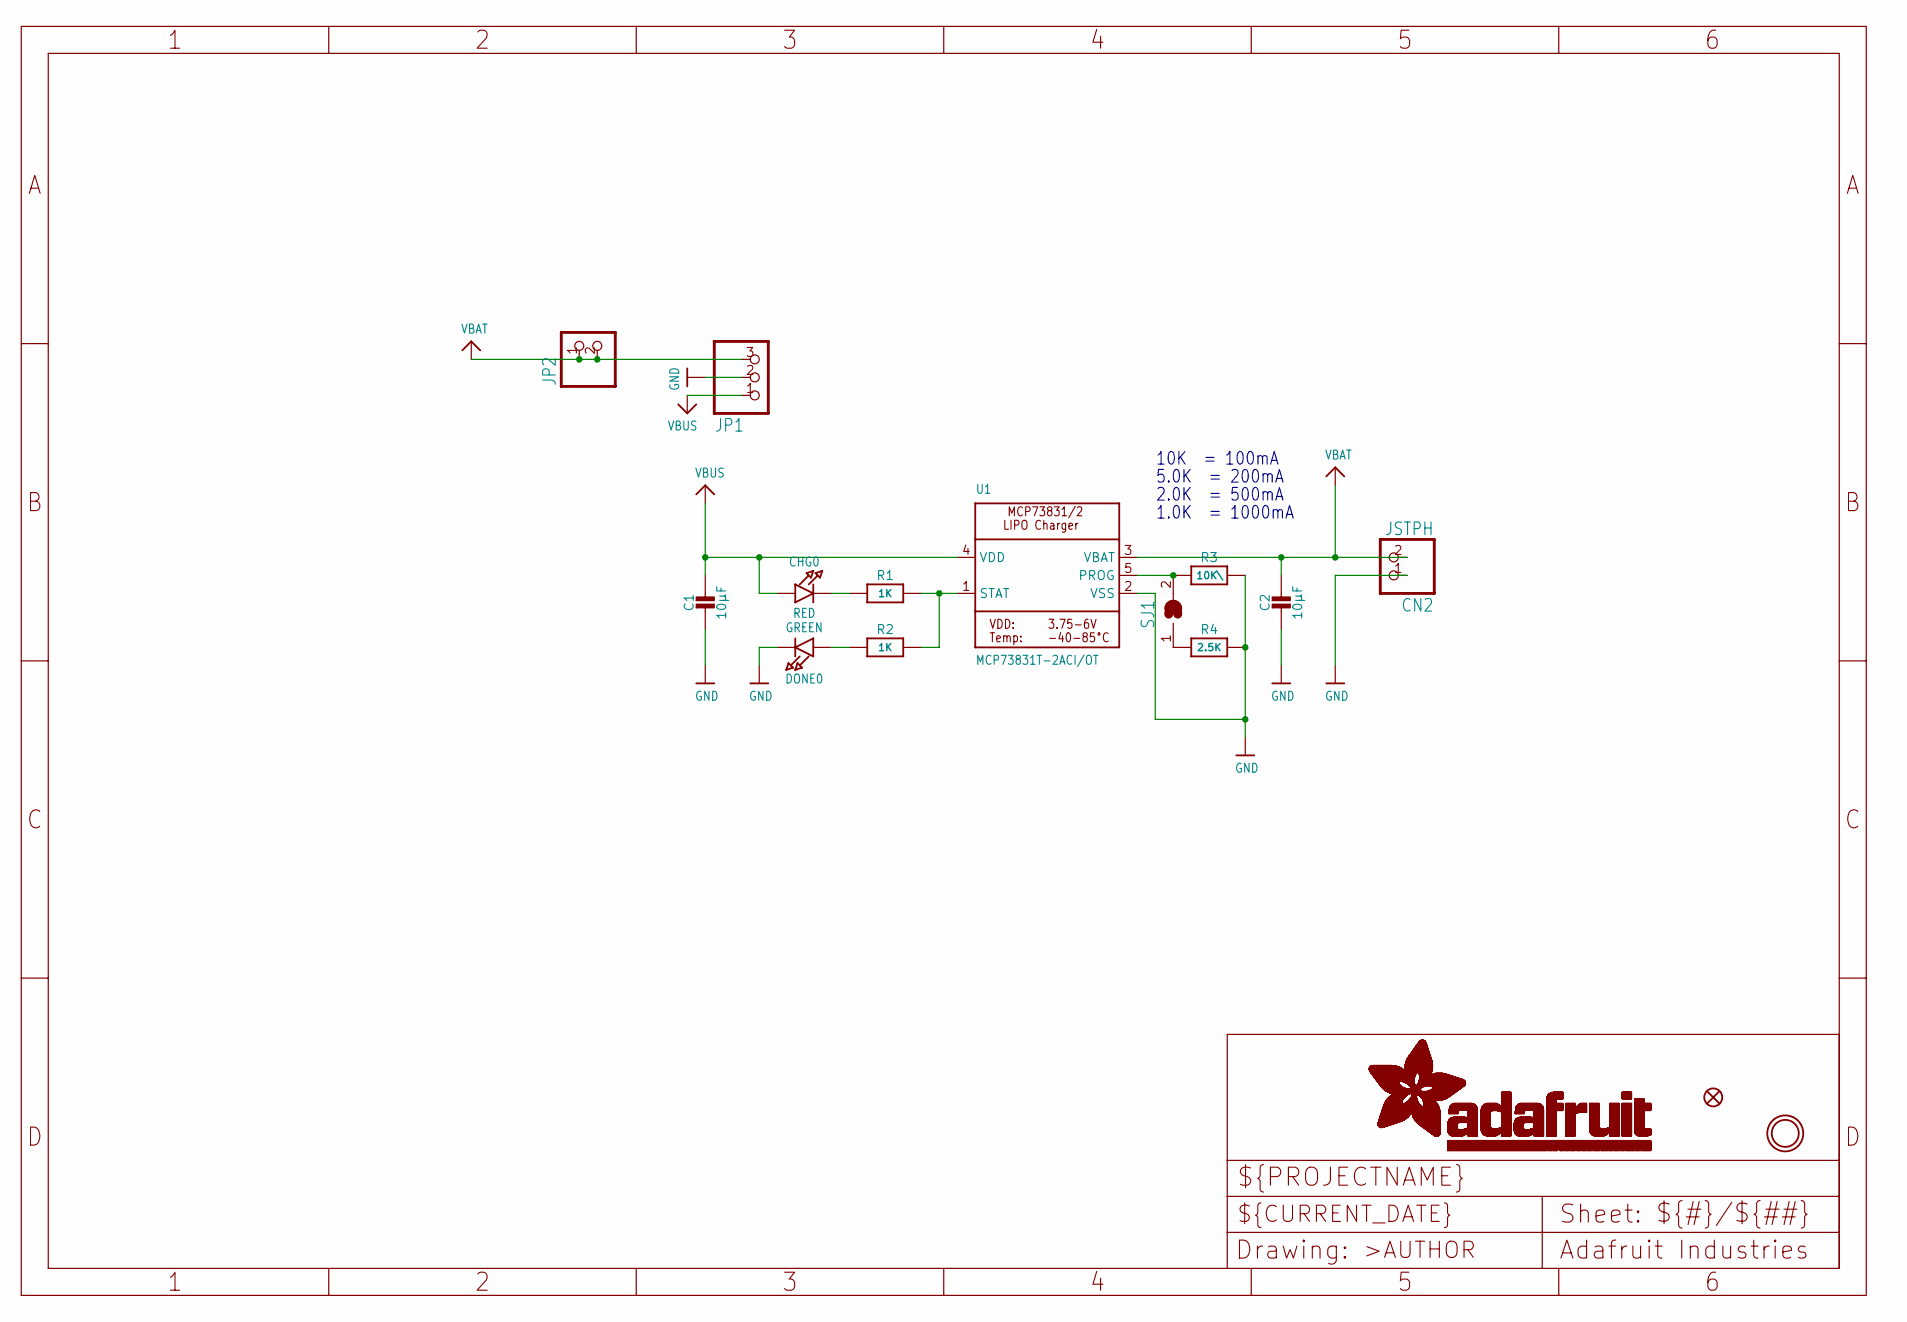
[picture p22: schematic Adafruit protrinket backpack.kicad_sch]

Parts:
C1, C2: 10µF; 0805-NO
CHG0: RED; CHIPLED_0805_NOOUTLINE
CN2: JSTPH; JSTPH2
DONE0: GREEN; CHIPLED_0805_NOOUTLINE
FID1: FIDUCIAL""; FIDUCIAL_1MM
JP1: HEADER-1X376MIL; 1X03_ROUND_76
JP2: HEADER-1X2ROUND; 1X02_ROUND
R1, R2: 1K; 0805-NO
R3: 10K\; _0805MP
R4: 2.5K; 0805-NO
SJ1: SOLDERJUMPER; SOLDERJUMPER_ARROW_NOPASTE
U1: MCP73831T-2ACI/OT; SOT23-5
U$10: MOUNTINGHOLE2.5; MOUNTINGHOLE_2.5_PLATED

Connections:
GND: C1.2, C2.2, CN2.1, DONE0.C, JP1.2, R3.2, R4.2, U1.2 (VSS)
unnamed: CHG0.C, R1.1
unnamed: R1.2, R2.2, U1.1 (STAT)
unnamed: R4.1, SJ1.1
unnamed: R3.1, SJ1.2, U1.5 (PROG)
unnamed: DONE0.A, R2.1
VBAT: C2.1, CN2.2, JP1.3, JP2.1, JP2.2, U1.3 (VBAT)
VBUS: C1.1, CHG0.A, JP1.1, U1.4 (VDD)

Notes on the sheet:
10K = 100mA
5.0K = 200mA
2.0K = 500mA
1.0K = 1000mA

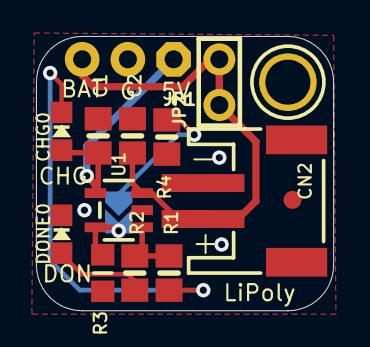
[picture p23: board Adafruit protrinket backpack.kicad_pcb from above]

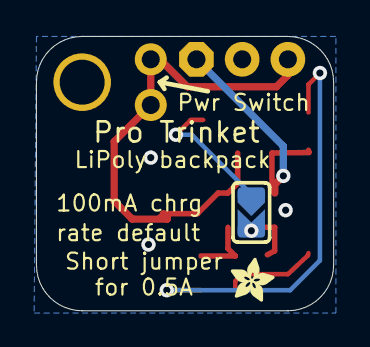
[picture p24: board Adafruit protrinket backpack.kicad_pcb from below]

Board: 2 copper layers, 16.5 x 15.2 mm, 16 parts (2 on the bottom side), 8 nets.

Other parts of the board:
U$9: ADAFRUIT_2.5MM

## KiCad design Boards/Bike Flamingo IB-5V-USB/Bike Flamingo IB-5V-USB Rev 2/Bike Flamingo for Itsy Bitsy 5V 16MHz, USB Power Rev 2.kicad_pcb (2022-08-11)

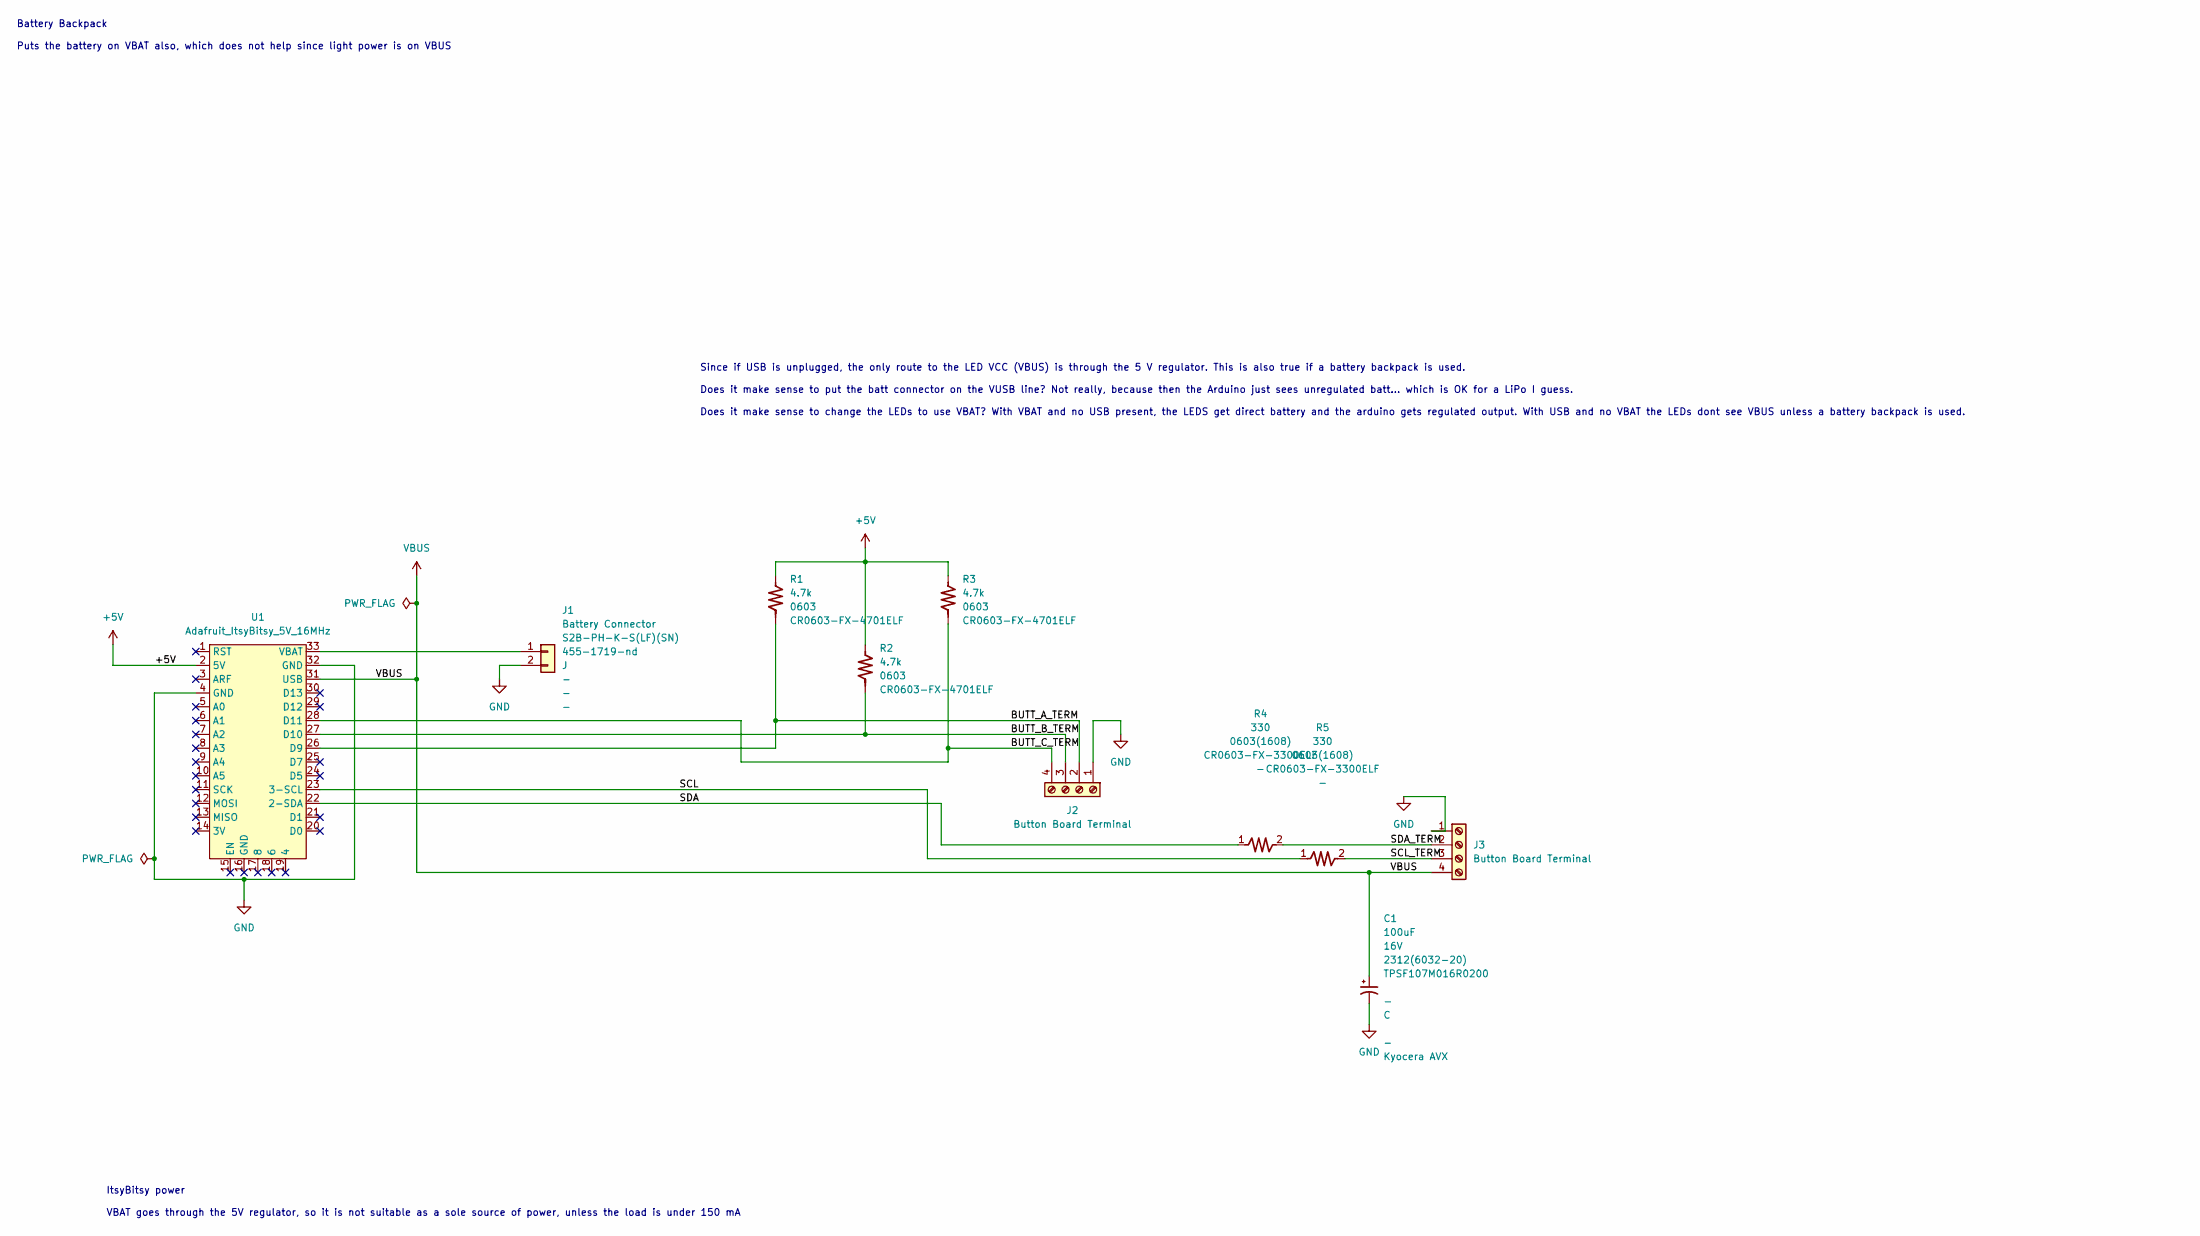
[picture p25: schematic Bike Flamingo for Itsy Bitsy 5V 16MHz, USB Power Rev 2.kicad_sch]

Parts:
C1: 100uF; CP_EIA-6032-28_Kemet-C_Pad2.25x2.35mm_HandSolder; Voltage Rating 16V; MFR P/N TPSF107M016R0200
J1: Battery Connector; JST_PH_S2B-PH-K_1x02_P2.00mm_Horizontal; MPN S2B-PH-K-S(LF)(SN); Digi-Key_PN 455-1719-nd
J2, J3: Button Board Terminal; TerminalBlock_TE_282834-4_1x04_P2.54mm_Horizontal; MFR PN 282834-4; DIGIKEY PN A98335-ND
R1, R2, R3: 4.7k; R_0603_1608Metric_Pad0.98x0.95mm_HandSolder; MPN CR0603-FX-4701ELF
R4, R5: 330; R_0603_1608Metric_Pad0.98x0.95mm_HandSolder; MPN CR0603-FX-3300ELF
U1: Adafruit_ItsyBitsy_5V_16MHz; Adafruit Itsy Bitsy 5V 16 MHz

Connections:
+5V: R1.1, R2.1, R3.1, U1.2 (5V)
/BUTT_A_TERM: J2.2, R1.2, U1.26 (D9)
/BUTT_B_TERM: J2.3, R2.2, U1.27 (D10)
/BUTT_C_TERM: J2.4, R3.2, U1.28 (D11)
/SCL: R5.1, U1.23 (3-SCL)
/SCL_TERM: J3.3, R5.2
/SDA: R4.1, U1.22 (2-SDA)
/SDA_TERM: J3.2, R4.2
GND: C1.2, J1.2, J2.1, J3.1, U1.4 (GND), U1.32 (GND)
unnamed: J1.1, U1.33 (VBAT)
VBUS: C1.1, J3.4, U1.31 (USB)

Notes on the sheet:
ItsyBitsy power VBAT goes through the 5V regulator, so it is not suitable as a sole source of power, unless the load is under 150 mA
Since if USB is unplugged, the only route to the LED VCC (VBUS) is through the 5 V regulator. This is also true if a battery backpack is used. Does it make sense to put the batt connector on the VUSB line? Not really, because then the Arduino just sees unregulated batt... which is OK for a LiPo I g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
Battery Backpack Puts the battery on VBAT also, which does not help since light power is on VBUS

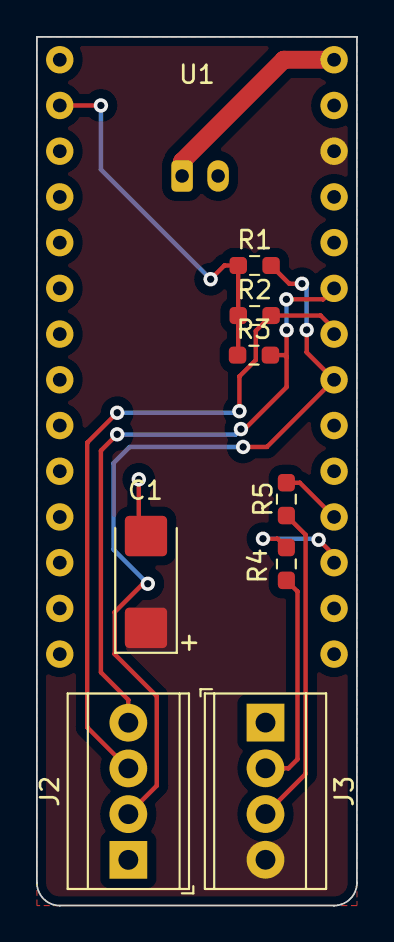
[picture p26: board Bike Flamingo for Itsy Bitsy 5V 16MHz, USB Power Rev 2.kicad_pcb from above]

Board: 2 copper layers, 17.8 x 48.3 mm, 10 parts (1 on the bottom side), 11 nets.

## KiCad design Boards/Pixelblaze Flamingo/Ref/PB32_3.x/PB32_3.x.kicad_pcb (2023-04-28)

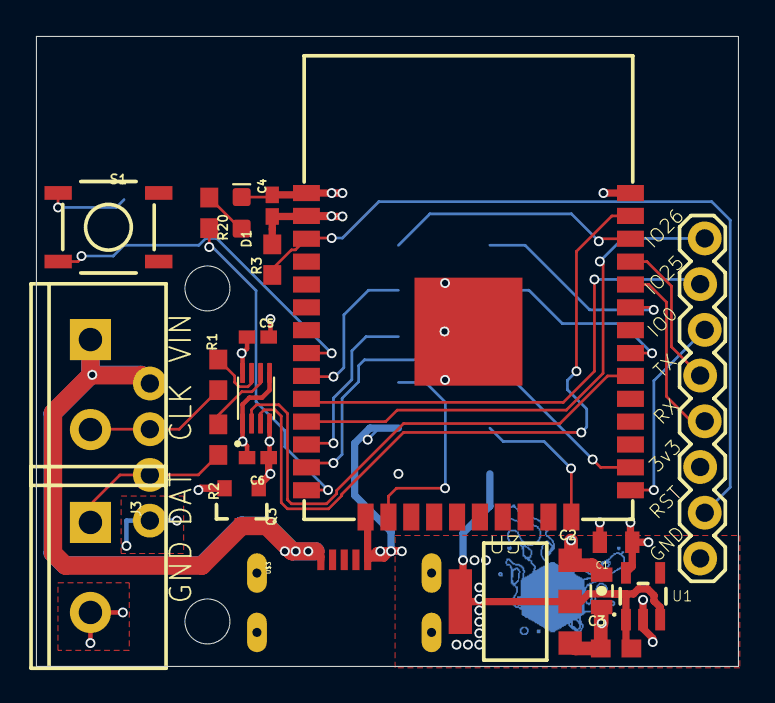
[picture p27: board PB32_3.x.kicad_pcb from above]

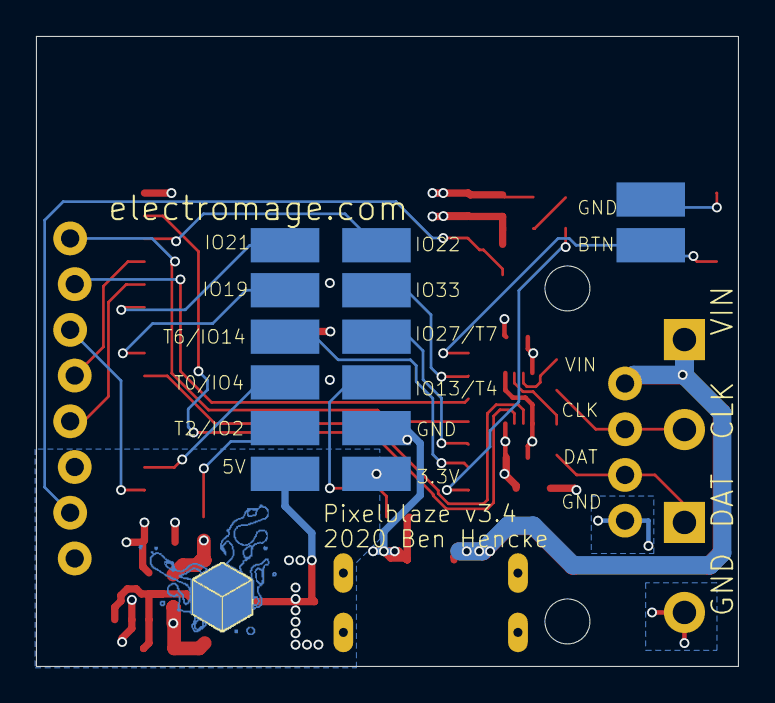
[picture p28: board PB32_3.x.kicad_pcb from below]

Board: 4 copper layers, 39.0 x 35.0 mm, 39 parts (15 on the bottom side), 29 nets.

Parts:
@HOLE0, @HOLE1: (no value)
C1: 1.0uF; 0805-CAP
C2: 10uF; 0805
C3: 4.7uF; 0603
C4, C5, C6: 0.1uF; C0402K
D1: LED-0603
GP1, GP3, GP6, GP8, GP9: PAD
IO2, IO4, IO13, IO14, IO19, IO21, IO22, IO27, IO33: PAD
J1: 1X08_LOCK
J2, J3: SCREWTERMINAL-5MM-2
J4: 1X04_NO_SILK
Q3: 2.5A/30V/105mΩ; SOT23-3
R1, R2, R20: 100; 0603
R3: 1k; 0603
S1: MOMENTARY-SWITCH-SPST-SMD-5.2MM; TACTILE_SWITCH_SMD_5.2MM
U1: AP2112K-3.3TRG1; SOT23-5
U2: ESP-WROOM-32
U3: NX1117C15Z; SOT223
U$1: SN74LVC2T45DCUR; SOP50P310X90-8N
U$2: ELECTRO_MAGE_PCB4_PIXEL_2#PNG
U$3: USB-CON-5PINUSB-SUNK-TIGHT; USB-SUNK-TIGHT

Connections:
+3V3: C2.1, C4.1, C6.1, GP1.P$1, J1.3, R3.2, U1.5, U2.2, U$1.1, U$1.5
+5V: C3.1, C5.1, GP6.P$1, U1.1, U1.3, U3.2, U3.4, U$1.8
BUTTON: GP8.P$1, S1.3, U2.8
EN: J1.2, R3.1, U2.3
GND: C1.2, C2.2, C3.2, C4.2, C5.2, C6.2, D1.C, GP3.P$1, GP9.P$1, J1.1, J3.2, J4.1, Q3.1, S1.1, U1.2, U2.1, U2.15, U2.38, U2.GND, U3.1, U$1.4, U$3.5
IO0: J1.6, U2.25
IO2: IO2.P$1, U2.24
IO4: IO4.P$1, U2.26
IO13: IO13.P$1, U2.16
IO14: IO14.P$1, U2.13
IO19: IO19.P$1, U2.31
IO21: IO21.P$1, U2.33
IO22: IO22.P$1, U2.36
IO25: J1.7, U2.10
IO26: J1.8, U2.11
IO27: IO27.P$1, U2.12
IO33: IO33.P$1, U2.9
LED: R20.2, U2.14
MOSI: U2.37, U$1.3
MOSI_OUT: J3.1, J4.2, R2.2
unnamed: C1.1, Q3.2, U3.3
unnamed: R1.1, U$1.7
unnamed: R2.1, U$1.6
unnamed: D1.A, R20.1
RX: J1.4, U2.34
SCK: U2.30, U$1.2
SCK_OUT: J2.2, J4.3, R1.2
TX: J1.5, U2.35
VIN: J2.1, J4.4, Q3.3, U$3.1

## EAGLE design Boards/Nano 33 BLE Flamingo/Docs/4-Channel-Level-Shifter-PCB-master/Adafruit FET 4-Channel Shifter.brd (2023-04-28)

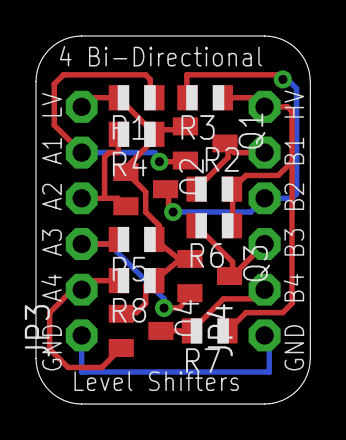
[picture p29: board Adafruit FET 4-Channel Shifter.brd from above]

Board: 2 copper layers, 15.2 x 20.4 mm, 15 parts (1 on the bottom side), 11 nets.

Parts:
JP3, JP4: 1X06-CLEANBIG
Q1, Q2, Q3, Q4: BSS138; SOT23
R1, R2, R3, R4, R5, R6, R7, R8: 10K; R0805
U$1: ADAFRUIT_3.5MM

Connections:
+3V3: JP3.6, Q1.1, Q2.1, Q3.1, Q4.1, R1.2, R4.1, R5.1, R8.1
+5V: JP4.6, R2.2, R3.1, R6.1, R7.1
GND: JP3.1, JP4.1
unnamed: JP4.3, Q3.3, R6.2
unnamed: JP4.5, Q1.3, R2.1
unnamed: JP3.3, Q3.2, R5.2
unnamed: JP3.2, Q4.2, R8.2
unnamed: JP4.2, Q4.3, R7.2
unnamed: JP3.4, Q2.2, R4.2
unnamed: JP4.4, Q2.3, R3.2
unnamed: JP3.5, Q1.2, R1.1

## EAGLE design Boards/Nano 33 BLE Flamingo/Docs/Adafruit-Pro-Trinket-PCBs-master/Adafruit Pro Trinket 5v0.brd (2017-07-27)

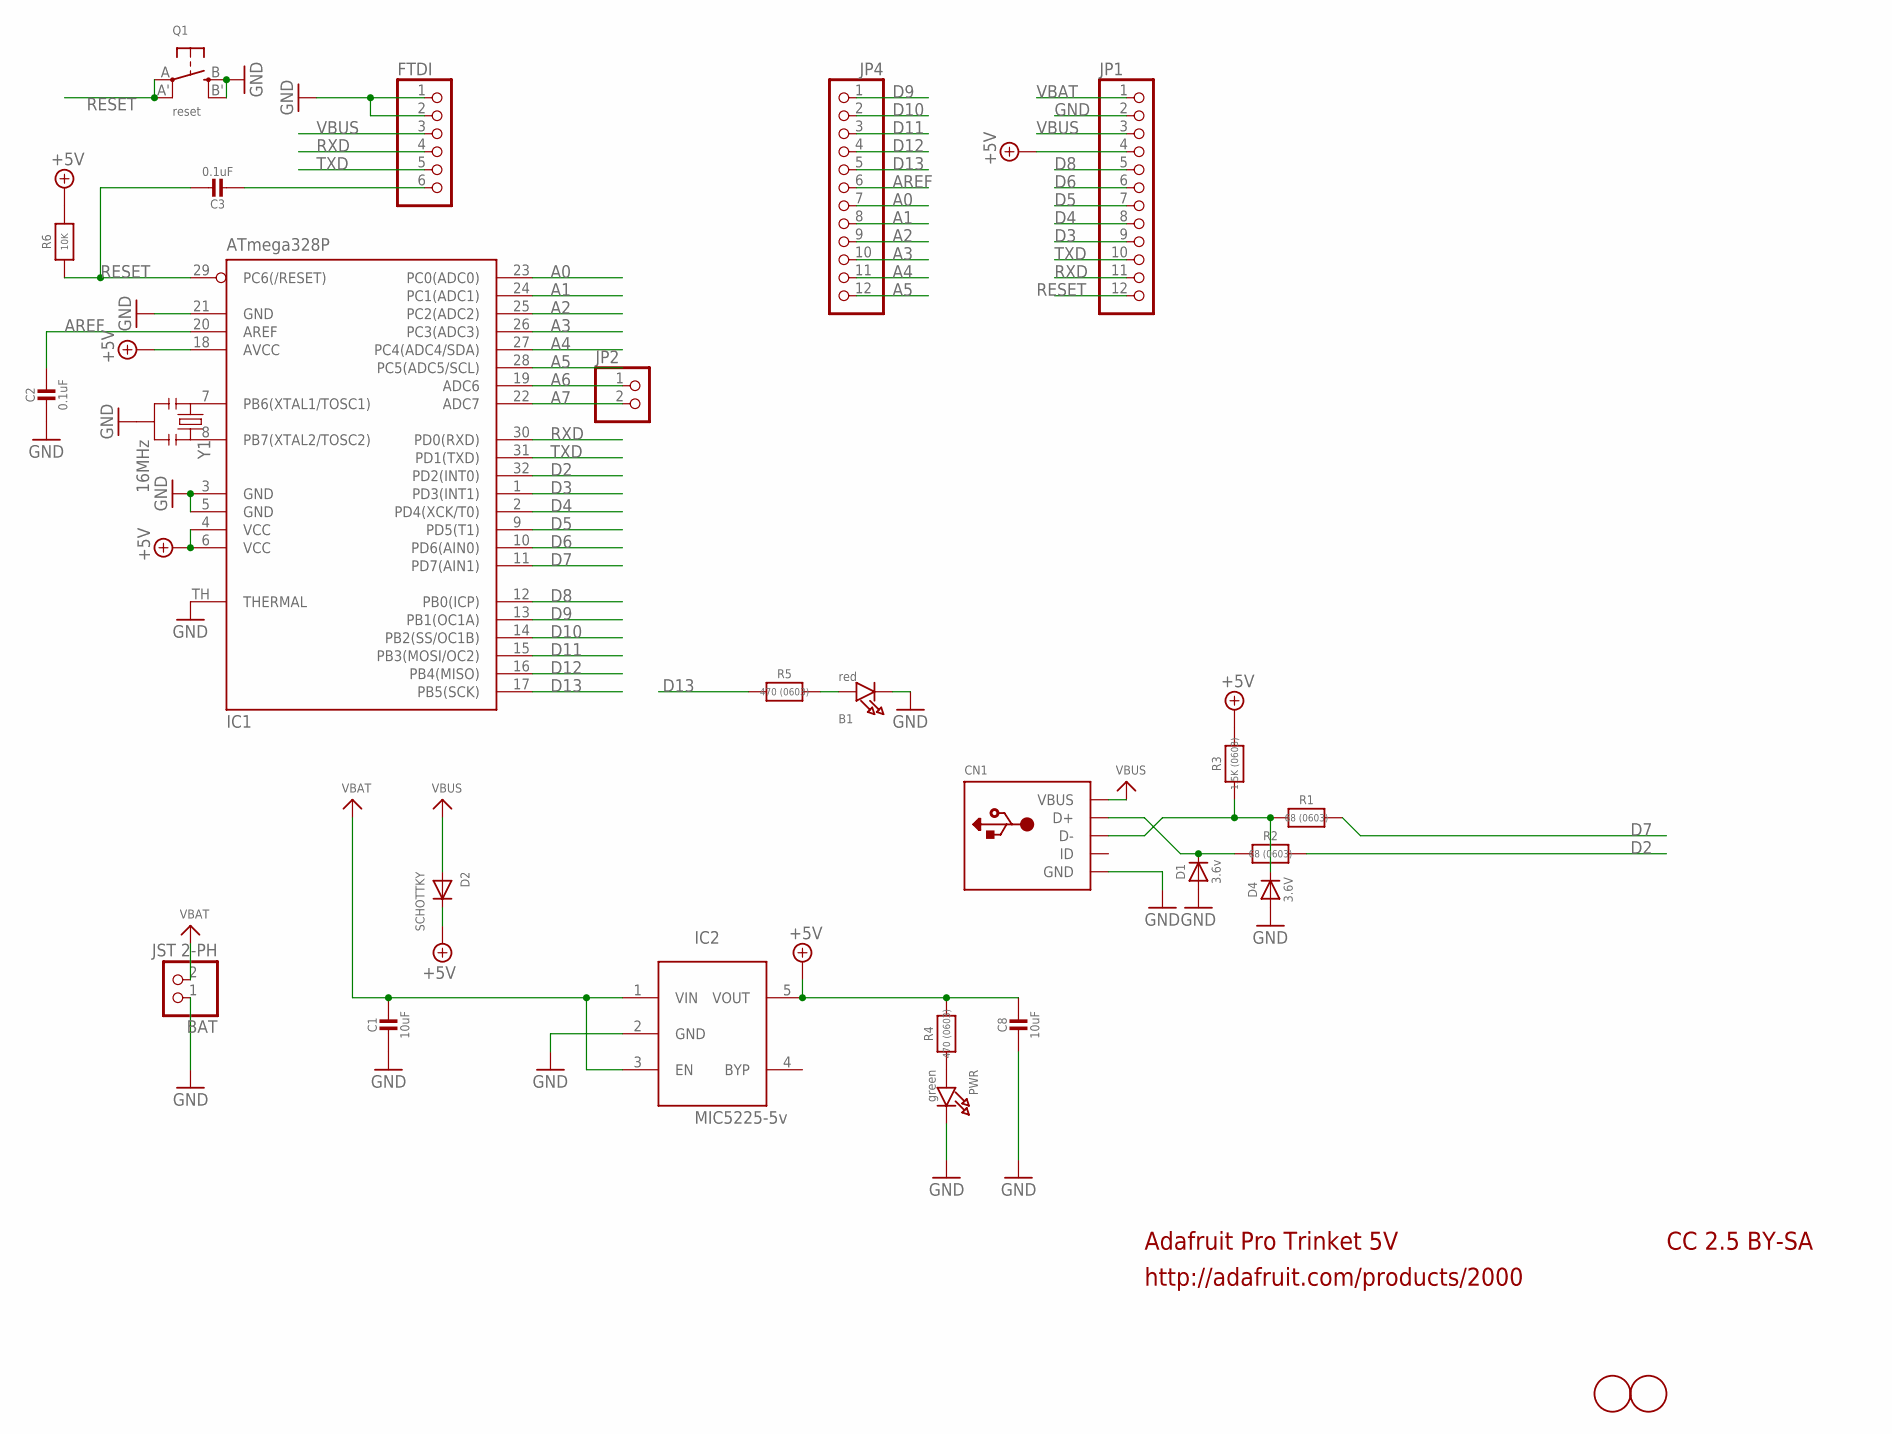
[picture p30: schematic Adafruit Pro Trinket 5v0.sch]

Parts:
B1: red; CHIPLED_0805_NOOUTLINE
BAT: JST 2-PH; JSTPH2
C1, C8: 10uF; 0805-NO
C2: 0.1uF; _0805MP
C3: 0.1uF; 0805-NO
CN1: USBMICRO_20329; 4UCONN_20329
D1: 3.6v; SOD-323
D2: SCHOTTKY; SOD-123FL
D4: 3.6V; SOD-323
FTDI: PINHD-1X6CB; 1X06-CLEANBIG
IC1: ATmega328P; MLF32-TH
IC2: MIC5225-5v; SOT23-5L
JP1, JP4: PINHD-1X12-CB; 1X12-CB
JP2: HEADER-1X2ROUND; 1X02_ROUND
PWR: green; CHIPLED_0805_NOOUTLINE
Q1: reset; BTN_KMR2_4.6X2.8
R1, R2: 68 (0603); 0603-NO
R3: 1.5K (0603); 0603-NO
R4, R5: 470 (0603); 0603-NO
R6: 10K; 0805-NO
U$1, U$6: FIDUCIAL; FIDUCIAL_1MM
Y1: 16MHz; RESONATOR-SMD

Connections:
+5V: C8.1, D2.C, IC1.4 (VCC), IC1.6 (VCC), IC1.18 (AVCC), IC2.5 (VOUT), JP1.4, R3.2, R4.2, R6.2
A0: IC1.23 (PC0(ADC0)), JP4.7
A1: IC1.24 (PC1(ADC1)), JP4.8
A2: IC1.25 (PC2(ADC2)), JP4.9
A3: IC1.26 (PC3(ADC3)), JP4.10
A4: IC1.27 (PC4(ADC4/SDA)), JP4.11
A5: IC1.28 (PC5(ADC5/SCL)), JP4.12
A6: IC1.19 (ADC6), JP2.1
A7: IC1.22 (ADC7), JP2.2
AREF: C2.1, IC1.20 (AREF), JP4.6
D2: IC1.32 (PD2(INT0)), R2.2
D3: IC1.1 (PD3(INT1)), JP1.9
D4: IC1.2 (PD4(XCK/T0)), JP1.8
D5: IC1.9 (PD5(T1)), JP1.7
D6: IC1.10 (PD6(AIN0)), JP1.6
D7: IC1.11 (PD7(AIN1)), R1.2
D8: IC1.12 (PB0(ICP)), JP1.5
D9: IC1.13 (PB1(OC1A)), JP4.1
D10: IC1.14 (PB2(SS/OC1B)), JP4.2
D11: IC1.15 (PB3(MOSI/OC2)), JP4.3
D12: IC1.16 (PB4(MISO)), JP4.4
D13: IC1.17 (PB5(SCK)), JP4.5, R5.2
D+: CN1.D+, D1.C, R2.1
D-: CN1.D-, D4.C, R1.1, R3.1
DTR/RTS: C3.2, FTDI.6
GND: B1.C, BAT.1, C1.2, C2.2, C8.2, CN1.BASE@1 (GND), CN1.BASE@2 (GND), CN1.GND, CN1.SPRT@1 (GND), CN1.SPRT@2 (GND), CN1.SPRT@3 (GND), CN1.SPRT@4 (GND), D1.A, D4.A, FTDI.1, FTDI.2, IC1.3 (GND), IC1.5 (GND), IC1.21 (GND), IC1.TH (THERMAL), IC2.2 (GND), JP1.2, PWR.C, Q1.B (S), Q1.B' (S1), Y1.2
unnamed: B1.A, R5.1
unnamed: IC1.8 (PB7(XTAL2/TOSC2)), Y1.3
unnamed: IC1.7 (PB6(XTAL1/TOSC1)), Y1.1
unnamed: PWR.A, R4.1
RESET: C3.1, IC1.29 (PC6(/RESET)), JP1.12, Q1.A, Q1.A' (P1), R6.1
RXD: FTDI.4, IC1.30 (PD0(RXD)), JP1.11
TXD: FTDI.5, IC1.31 (PD1(TXD)), JP1.10
VBAT: BAT.2, C1.1, IC2.1 (VIN), IC2.3 (EN), JP1.1
VBUS: CN1.VBUS, D2.A, FTDI.3, JP1.3

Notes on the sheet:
Adafruit Pro Trinket 5V
http://adafruit.com/products/2000
CC 2.5 BY-SA

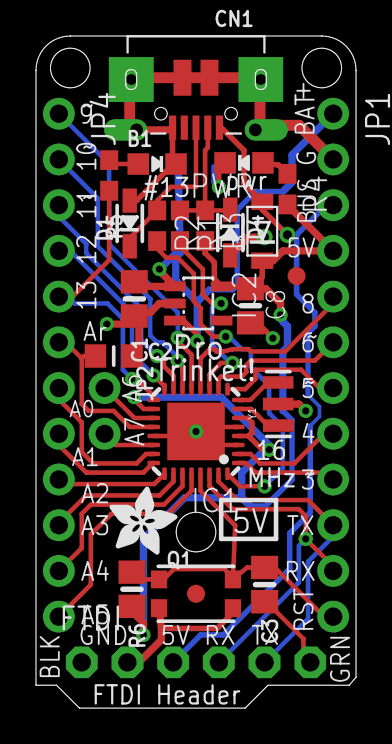
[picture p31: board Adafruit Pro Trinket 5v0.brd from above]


Board: 2 copper layers, 17.8 x 37.3 mm, 29 parts (2 on the bottom side), 35 nets.

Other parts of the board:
U$7: ADAFRUIT_3.5MM
U$9: ADAFRUIT_9MM

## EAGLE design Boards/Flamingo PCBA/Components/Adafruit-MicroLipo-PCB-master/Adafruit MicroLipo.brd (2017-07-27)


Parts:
C1, C2: 10µF; 0805
CN1: USB_TYPEAPCB; USBA_PCB
CN2: JSTPH; JSTPH2
FID1: FIDUCIAL""; FIDUCIAL_1MM
LED1: RED; CHIPLED_0805
LED2: GREEN; CHIPLED_0805
R1, R2: 470; 0805
R3: 10K\; 0805
R4: 2K; 0805
SJ1: SOLDERJUMPER; SOLDERJUMPER_ARROW_NOPASTE
U1: MCP73831T-2ACI/OT; SOT23-5

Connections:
GND: C1.2, C2.2, CN1.GND, CN2.1, LED2.C, R3.2, R4.2, U1.2 (VSS)
unnamed: LED1.C, R1.1
unnamed: R1.2, R2.2, U1.1 (STAT)
unnamed: R4.1, SJ1.1
unnamed: R3.1, SJ1.2, U1.5 (PROG)
unnamed: LED2.A, R2.1
VBAT: C2.1, CN2.2, U1.3 (VBAT)
VDD: C1.1, CN1.VCC (VBUS), LED1.A, U1.4 (VDD)

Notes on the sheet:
10K = 100mA
5.0K = 200mA
2.0K = 500mA
1.0K = 1000mA



Board: 2 copper layers, 30.4 x 12.1 mm, 14 parts (2 on the bottom side), 8 nets.

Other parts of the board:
U$8: ADAFRUIT_TEXT_20MM

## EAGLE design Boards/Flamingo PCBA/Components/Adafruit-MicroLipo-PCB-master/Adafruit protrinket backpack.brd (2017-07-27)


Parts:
C1, C2: 10µF; 0805-NO
CHG: RED; CHIPLED_0805_NOOUTLINE
CN2: JSTPH; JSTPH2
DONE: GREEN; CHIPLED_0805_NOOUTLINE
FID1: FIDUCIAL""; FIDUCIAL_1MM
JP1: HEADER-1X376MIL; 1X03_ROUND_76
JP2: HEADER-1X2ROUND; 1X02_ROUND
R1, R2: 1K; 0805-NO
R3: 10K\; _0805MP
R4: 2.5K; 0805-NO
SJ1: SOLDERJUMPER; SOLDERJUMPER_ARROW_NOPASTE
U1: MCP73831T-2ACI/OT; SOT23-5
U$10: MOUNTINGHOLE2.5; MOUNTINGHOLE_2.5_PLATED

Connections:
GND: C1.2, C2.2, CN2.1, DONE.C, JP1.2, R3.2, R4.2, U1.2 (VSS)
unnamed: CHG.C, R1.1
unnamed: R1.2, R2.2, U1.1 (STAT)
unnamed: R4.1, SJ1.1
unnamed: R3.1, SJ1.2, U1.5 (PROG)
unnamed: DONE.A, R2.1
VBAT: C2.1, CN2.2, JP1.3, JP2.1, JP2.2, U1.3 (VBAT)
VBUS: C1.1, CHG.A, JP1.1, U1.4 (VDD)

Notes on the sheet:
10K = 100mA
5.0K = 200mA
2.0K = 500mA
1.0K = 1000mA



Board: 2 copper layers, 16.5 x 15.2 mm, 16 parts (2 on the bottom side), 8 nets.

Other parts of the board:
U$9: ADAFRUIT_2.5MM

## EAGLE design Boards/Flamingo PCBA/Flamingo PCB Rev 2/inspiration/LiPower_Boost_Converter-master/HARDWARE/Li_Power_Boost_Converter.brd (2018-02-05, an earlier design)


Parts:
C1: 10uF; 1206
C2, C4: 0.1uF; 0603-CAP
C3: 22uF; 0805
FRAME1: FRAME-LETTER; CREATIVE_COMMONS
JP1: VOUT; 1X02
JP2: LOGO-SFESK; SFE-LOGO-FLAME
JP3: JST; JST-2-SMD
JP4, JP5: FIDUCIAL1X2; FIDUCIAL-1X2
JP6: LOGO-SFENEW; SFE-NEW-WEBLOGO
JP7: VIN; 1X02
L1: 4.7uH, 1.2A; CDRH2D09
R3, R7: 2M; 0603-RES
R4, R6: 220k; 0603-RES
R5: 1.2M; 0603-RES
SJ1: SOLDERJUMPER_2WAYPASTE2&3; SJ_3_PASTE2&3
U1: TPS61200; QFN-10_PAD

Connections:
3.3V: R5.1, SJ1.1
5V: R7.1, SJ1.3
FB: R6.2, SJ1.2, U1.10 (FB)
GND: C1.2, C3.2, C4.2, JP1.1, JP3.1, JP7.1, R4.1, R6.1, U1.4 (PGND), U1.9 (GND), U1.11 (PAD), U1.12 (PAD), U1.13 (PAD), U1.14 (PAD), U1.15 (PAD)
unnamed: C4.1, U1.1 (VAUX)
unnamed: L1.P$1 (1), U1.3 (L)
UVLO: C2.2, R3.1, R4.2, U1.7 (UVLO)
VCC: C3.1, JP1.2, R5.2, R7.2, U1.2 (VOUT)
VIN: C1.1, C2.1, JP3.2, JP7.2, L1.P$2 (2), R3.2, U1.5 (VIN), U1.6 (EN), U1.8 (PS)

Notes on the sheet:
UVLO 2.6V
circuitsathome.com
Oleg Mazurov
Aaron Weiss
sparkfun.com
V12
Revised by Patrick Alberts



Board: 2 copper layers, 26.7 x 12.7 mm, 21 parts (2 on the bottom side), 9 nets.

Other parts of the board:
U$2: OSHW-LOGO-S

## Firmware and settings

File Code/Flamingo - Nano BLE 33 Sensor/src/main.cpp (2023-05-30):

#include <Arduino.h>

#include <parameters.h>
#include <function_declarations_and_globals.h>

/*   TODO

Lowest brightness is perfectly adequate for  festival in general, might even consider a lower brightness?
Fix bouncing ball at bottom


*/

/*

About 700 Hz with just 3-button polling and serial out.

syncradnnum program, flowing or fast flowing rainbow, setting 3? max brightness.

 Attom Tech smaller 3000mAh     255 brightness  1723mAh 2h 31
                                150 brightness  1683mAh 3h 30
 Kolumb 2500mAh                 255 brightness  1274mAh 1h 48

For atomtek 3000 mAh battery				
brightness	brightness%	time	hours	hours Kolumb
10	0.04	290.27	4.84	3.41
20	0.08	284.55	4.74	3.35
30	0.12	278.82	4.65	3.28
40	0.16	273.10	4.55	3.21
50	0.20	267.37	4.46	3.15
60	0.24	261.65	4.36	3.08
70	0.27	255.92	4.27	3.01
80	0.31	250.20	4.17	2.94
90	0.35	244.47	4.07	2.88
100	0.39	238.75	3.98	2.81
110	0.43	233.02	3.88	2.74
120	0.47	227.29	3.79	2.67
130	0.51	221.57	3.69	2.61
140	0.55	215.84	3.60	2.54
150	0.59	210.12	3.50	2.47
160	0.63	204.39	3.41	2.40
170	0.67	198.67	3.31	2.34
180	0.71	192.94	3.22	2.27
190	0.75	187.22	3.12	2.20
200	0.78	181.49	3.02	2.14
210	0.82	175.76	2.93	2.07
220	0.86	170.04	2.83	2.00
230	0.90	164.31	2.74	1.93
240	0.94	158.59	2.64	1.87
250	0.98	152.86	2.55	1.80
255	1.00	150.00	2.50	1.76

HOW TO CONNECT EVERYTHING

********* Buttons *********
BAT -> Resistor -> (Button Pin) -> (Normally Open Button) -> GND

********* Dotstars/APA102C *********
Electrolytic cap across VCC and GND

(Adafruit 144/m, on Flamingo Original stick):
VCC -> BAT
Green/data -> 11 (Hardware SPI MOSI)
Yellow/clock -> 13 (Hardware SPI CLOCK)
GND to GND

APA102C 144/m (chinese):
VCC -> BAT
Green/data -> 11 (Hardware SPI MOSI)
Red/clock -> 13 (Hardware SPI CLOCK)
GND to GND
*/

/////// GENERAL ////
//
//
//

// for time()

// uint32_t start_time = 0;

// #define numberofprograms 2

// uint8_t volatile programIndex = 0;

// bool firstRun = 1;

// Globals

bool first_program_run = 1;
uint8_t programIndex = 0;
uint8_t settingIndex = 0;
uint8_t brightnessIndex = 0;

float brightnessArray[GLOBAL_BRIGHTNESS_LEVELS_NUMBER] = GLOBAL_BRIGHTNESS_LEVELS;

// This version uses hardware SPI
// With just DHO single pixel:
// 81.97 Hz, 12.2 ms for 72 LEDs, 1 strand
// 6.8 ms for LED data, 5.44 ms for DHO single pixel loop
//
Adafruit_DotStar strip(NUMPIXELS, DOTSTAR_BGR);

void setup()
{

    //////////////////// Serial ////////////////////

    Serial.begin(115200);

    delay(100);
    Serial.println(F("Started serial to PC."));

    //////////////////// Buttons ////////////////////

    buttons_initialize();

    //////////////////// IMU ////////////////////

    if (!imu_initialize())
    {
        Serial.println(F("IMU failed to initialize."));
        while (1)
            ;
    }

    imu_active = 1;
    mag_active = 0;
    gflash_active = 1;

    //////////////////// LEDs ////////////////////

    strip.begin(); // Initialize pins for output
    strip.clear();
    strip.setBrightness(brightnessArray[0]);
    strip.show(); // Turn all LEDs off ASAP

    //////////////////// Timing ////////////////////

    timing_update_variables();
}

uint8_t counter = 0;

void loop()
{
    // Serial.print(first_program_run);
    // Serial.print("\t");
    // Serial.println(imu_active);
    //////////////////// Buttons ////////////////////

    // This calls button_X_action() in buttons.cpp
    buttons_check_for_changes();

    //////////////////// IMU ////////////////////

    if (imu_active)
    {
        imu_update_accel_values();
    }

    if (mag_active)
    {
        mag_update_mag_values();
    }

    //////////////////// Timing ////////////////////

    // This updates time_interval_us with the loop interval
    timing_update_variables();

    //////////////////// Programs ////////////////////
    //////////////////////////////////////////////////

    switch (programIndex)
    {

        ///////////////////////  DHO  ///////////////////////
    case 0:
    {

        if (first_program_run)
        {
            Serial.println(F("In Case 0"));

            imu_active = 1;
            mag_active = 0;
            gflash_active = 0;

            settingIndex = 0;
            DHO_main_program();
            first_program_run = 0;

            break;
        }

        DHO_main_program();

        /* counter++;
         if (counter == 0)
         {
             Serial.println(time_frequency_hz);
         }
         */

        break;
    };

        ///////////////////////  BB  ///////////////////////
    case 1:
    {

        if (first_program_run)
        {
            Serial.println(F("In Case 1"));

            imu_active = 1;
            mag_active = 0;
            gflash_active = 0;

            settingIndex = 0;
            BB_main_program();
            first_program_run = 0;

            break;
        }

        BB_main_program();

        break;
    };

        ///////////////////////  GFLASH  ///////////////////////
    case 2:
    {

        if (first_program_run)
        {
            Serial.println(F("In Case 2"));

            imu_active = 1;
            mag_active = 0;
            gflash_active = 1;

            settingIndex = 0;
            GFLASH_main_program();
            first_program_run = 0;

            break;
        }

        GFLASH_main_program();

        break;
    };

        ///////////////////////  SYNCRANDNUM  ///////////////////////
    case 3:
    {

        if (first_program_run)
        {
            Serial.println(F("In Case 3"));

            imu_active = 1;
            mag_active = 0;
            gflash_active = 1;

            settingIndex = 0;
            SYNCRANDNUM_main_program();
            first_program_run = 0;

            break;
        }

        SYNCRANDNUM_main_program();

        break;
    };

        ///////////////////////  FIRE  ///////////////////////
    case 4:
    {

        if (first_program_run)
        {
            Serial.println(F("In Case 4"));

            imu_active = 0;
            mag_active = 0;
            gflash_active = 0;

            settingIndex = 0;
            FIRE_main_program();
            first_program_run = 0;

            break;
        }

        FIRE_main_program();

        break;
    };

        ///////////////////////  SPARKLE  ///////////////////////
    case 5:
    {

        if (first_program_run)
        {
            Serial.println(F("In Case 5"));

            imu_active = 1;
            mag_active = 0;
            gflash_active = 1;

            settingIndex = 0;
            SPARKLE_main_program();
            first_program_run = 0;

            break;
        }

        SPARKLE_main_program();

        break;
    };

    ///////////////////////  Timing  ///////////////////////
    /*
    case 6:
    {

        if (first_program_run)
        {
            Serial.println(F("In Case 6"));

            imu_active = 0;
            mag_active = 0;
            gflash_active = 0;

            settingIndex = 0;

            first_program_run = 0;

            break;
        }

        Serial.print(DHO_COLOR);
        Serial.print("\t");
        uint32_t color_hue = strip.ColorHSV(55000, 255, 255);
        Serial.println(color_hue);

        strip.clear();
        for (int i = 0; i < NUMPERSTRAND / 2.0; i++)
        {
            // uint32_t color = strip.ColorHSV(hue_angle, 255 -gflash_factor * 30.0, brightness);
            // COMMON_SetPixelByStrandIndex(i, strip.ColorHSV(55000, 255, 255));
            COMMON_SetPixelByStrandIndex(i, DHO_COLOR);
        }
        for (int i = NUMPERSTRAND / 2.0; i < NUMPERSTRAND; i++)
        {
            // uint32_t color = strip.ColorHSV(hue_angle, 255 -gflash_factor * 30.0, brightness);
            // COMMON_SetPixelByStrandIndex(i, strip.ColorHSV(55000, 255, 255));
            COMMON_SetPixelByStrandIndex(i, color_hue);
        }
        strip.show();

        // counter++;
        // if (counter == 0)
        //{
        //     Serial.println(time_interval_us);
        // }

        break;
    };
*/
    default:
    {
        Serial.print(F("We fell into default case, programIndex is "));
        Serial.println(programIndex);
    };
    };
};

// Takes an index from 0 to NUMPERSTRAND -1 and sets all three strands.
void COMMON_SetPixelByStrandIndex(uint16_t index, uint32_t color)
{
    if ((index >= 0) && (index < NUMPERSTRAND))
    {
        // index goes from 0 to NUMPERSTRAND - 1
        uint16_t realindex = 0;

#if NUM_STRANDS == 1
        realindex = index;
        strip.setPixelColor(realindex, color);
        // Serial.println(color_h, HEX);
#endif

#if NUM_STRANDS == 3
        // NUMPERSTRAND - 1
        // 0
        realindex = NUMPERSTRAND - index - 1;
        strip.setPixelColor(realindex, color);
        // Serial.print(realindex);
        // Serial.print("\t");

        // NUMPERSTRAND
        // 2*NUMPERSTRAND - 1
        realindex = NUMPERSTRAND + index;
        strip.setPixelColor(realindex, color);
        // Serial.print(realindex);
        // Serial.print("\t");

        // 3*NUMPERSTRAND - 1
        // 2*NUMPERSTRAND
        realindex = 3 * NUMPERSTRAND - index - 1;
        strip.setPixelColor(realindex, color);
        // Serial.println(realindex);
#endif
    }
}

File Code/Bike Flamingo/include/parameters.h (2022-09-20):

#ifndef PARAMETERS_H
#define PARAMETERS_H

#include <ADXL345.h>
#include <Arduino.h>
#include <FastLED.h>
#include <I2Cdev.h>
#include <MPU6050.h>
#include <SPI.h>

#include <Wire.h>
#include <avr/pgmspace.h>
#include <math.h>

#include <accel.h>
#include <bouncing_balls.h>
#include <buttons.h>
#include <harmonic_oscillator.h>
#include <parameters.h>
#include <programs-common.h>
#include <utils.h>

#define DEBUG 1





// Board Types
// Board Type 1: Bike Flamingo 2022 Rev 1. ItsyBitsy 5V, 3 buttons. On bike. 216 pixels.
// Board Type 2: Bike Flamingo 2022 Rev 1. ItsyBitsy 5V, 3 buttons. On tent. 288 Pixels.
// Board Type 3: Flamingo totem.

#define BOARD_TYPE 1




//////////// BOARD TYPE 1 ////////////////////////
// 1 = Bike Flamingo 2022 Rev 1
// ItsyBitsy 5V, 3 buttons
#if BOARD_TYPE == 1

#define NUM_STRANDS 1
#define NUM_PROGRAMS 4


// Brightness stuff

#define BRIGHTNESS_MAX_QUANTITY 10 // max number of brightness levels across all programs
// All brightness arrays have 10 elements. When the value is 0, it cycles back. Therefore all must end with 0
#define ALL_BRIGHTNESS_ARRAY                                                                                                        \
  {                                                                                                                                 \
    {10, 100, 255, 0, 0, 0, 0, 0, 0, 0}, {10, 140, 240, 0, 0, 0, 0, 0, 0, 0}, { 10, 15, 20, 40, 60, 100, 140, 180, 240, 0 },  {10, 100, 255, 0, 0, 0, 0, 0, 0, 0}\
  }
// NO "RUN_ON_TOTEM" defined here
extern uint8_t brightnessIndex[NUM_PROGRAMS];


// Buttons
//#define BUTTON1 3
//#define BUTTON2 4
#define BUTT_A 9
#define BUTT_B 10
#define BUTT_C 11

#define DEBOUNCE_DELAY 100

// FastLED stuff
//#define NUMPIXELS 144    // Number of LEDs in strip
//#define NUMPIXELS 29    // Number of LEDs in strip
#define NUMPIXELS 288    // Number of LEDs in strip
#define NUMPERSTRAND 288 // Assuming 1 strands for bike Flamingo
//#define NUMPERSTRAND 48 // Assuming 3 strands for Flamingo
//#define CLOCK_PIN 13
//#define DATA_PIN 11
#define CLOCK_PIN 3
#define DATA_PIN 2

#define COLOR_ORDER BGR // my strip is BGR
#define CORRECTION TypicalLEDStrip
//#define CORRECTION UncorrectedColor

// time()
extern uint32_t start_time;

// Synchronized Random Numbes Rainbow varliables

// Harmonic oscillator parameters
//#define SPRINGCONSTANT 2
//#define DAMPING 0.4f
//#define MAXRANGE 15.0f
//#define MAXRANGE_REAL 1.0f
//#define SPRINGCONSTANT_REAL 1.0f  // 1.0
//#define DAMPING_REAL 0.3f         // 0.3
//#define MASS_REAL 4.0f            // 4.0

// Green Fire parameters
#define GFIRE_COOLING 55
#define GFIRE_SPARKING 120
#define GFIRE_SPEEDDELAY 15

// Fire W PALLETTE parameters
#define FIRE_PALLETTE_COOLING 70
#define FIRE_PALLETTE_SPARKING 120

// Sparkle Fizz
#define MAX_G_SPARKLEFIZZ 1.0f        // acceleration in m/sˆ2 for max sparkle
#define MAX_INTERVAL_SPARKLEFIZZ 1300 // longest without a sparkle
#define JITTER_SPARKLEFIZZ \
  200 // random interval in ms to add to inter-sparkle time
#define ACC_MAX_DECAY_RATE \
  20000.0f // A0 * exp( - t/AVG_DECAY_RATE), in ms, sets decay rate of
           // acceleration max

// DHO_Comet
//#define NUM_HISTORY 100

// DHO_Fade
//#define FADE_COEF 240

// Bouncy Balls
//#define NUM_BOUNCYBALLS 1
//#define BB_DAMPING 0.2f
//#define G_ACC_MAGNITUDE_BB 1412.64  // 9.81

// General variables
extern uint8_t counter;
extern uint32_t timer;
extern uint8_t counter_every_10_8;
extern uint32_t last_interrupt_time;

// ADXL345/GY-291 variables
extern ADXL345 accel;

extern int16_t ay;
extern float g0y, gy, acc_offset_normalized;

// Button variables
extern uint8_t button1state;
extern uint8_t button2state;
extern uint8_t button1prevstate;
extern uint8_t button2prevstate;

extern unsigned long timeNowButton1;
extern unsigned long timeNowButton2;
extern unsigned long lastTimePressedButton1;
extern unsigned long lastTimePressedButton2;

extern volatile bool firstRun;

extern volatile uint8_t programIndex; // start at 0

// FastLED/Dotstar/APA102C variables
// extern uint32_t color;
extern CRGB color;
extern CRGB leds[NUMPIXELS];

// Harmonic oscillator variables
extern float pos0, pos1, vel0, vel1, acc0, acc1, acc_ext;
extern float timenow_f, timestep_f, timestep_i;
extern uint16_t timeold_i, timenow_i;
extern bool first_iter;

// Sparkle fizz variables
extern uint16_t sparkleInterval;
extern float acc_max; // Maximum acceleration, decay rate set by AVG_DECAY_RATE
extern uint16_t acc_max_timeold;
extern uint16_t acc_max_timenew;
extern uint16_t sparkle_timeold;
extern uint16_t sparkle_timenew;
extern uint16_t sparkleInterval_max;

// Fire with Pallette variables
// Fire W PALLETTE parameters
#define FIRE_PALLETTE_COOLING 70
#define FIRE_PALLETTE_SPARKING 120

// Rainbow variables
extern byte *c;
extern uint16_t jrainbow;


#endif // BOARD_TYPE = 1


////////////////////////////////////////////////////////////



#if BOARD_TYPE == 3
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

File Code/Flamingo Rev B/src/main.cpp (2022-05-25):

#include <ADXL345.h>
#include <Arduino.h>
#include <FastLED.h>
#include <I2Cdev.h>
#include <MPU6050.h>
#include <SPI.h>
#include <Wire.h>
#include <avr/pgmspace.h>
#include <math.h>

#include <accel.h>
#include <buttons.h>
#include <harmonic_oscillator.h>
#include <parameters.h>
#include <programs-common.h>
#include <utils.h>

// To use serial or not
#define PLOT 1

/*
 HOW TO CONNECT EVERYTHING

  ********* ADXL345 *********
  Adafruit Pro Trinket 5V w/ battery backpack:
  CS -> BAT
  SDO -> GND
  SDA -> A4 (I2C SDA)
  SCL -> A5 (I2C SCL)
  VCC -> BAT
  GND -> GND

  Arduino Uno:
  CS ->3V3
  SDO -> GND
  SDA -> A4 (I2C SDA)
  SCL -> A5 (I2C SCL)
  VCC ->3V3
  GND -> GND
  10k between VCC and SCL ??
  10k between VCC and SDA ??

  ********* Buttons *********
  BAT -> Resistor -> (Button Pin) -> (Normally Open Button) -> GND

  ********* Dotstars/APA102C *********
  Electrolytic cap across VCC and GND

  (Adafruit 144/m, on Flamingo Original stick):
  VCC -> BAT
  Green/data -> 11 (Hardware SPI MOSI)
  Yellow/clock -> 13 (Hardware SPI CLOCK)
  GND to GND

  APA102C 144/m (chinese):
  VCC -> BAT
  Green/data -> 11 (Hardware SPI MOSI)
  Red/clock -> 13 (Hardware SPI CLOCK)
  GND to GND
*/

/////// GENERAL ////
//
//
//

uint32_t timer = 0;
uint8_t counter = 0;
uint16_t counter16 = 0;
uint8_t counter_every_10_8 = 0;

////////////////////   FastLED / APA102C   //////////////////
//

CRGB leds[NUMPIXELS];

////////////////////// ADXL345 /////////////////////////
// class default I2C address is 0x53
// specific I2C addresses may be passed as a parameter here
// ALT low = 0x53 (default for SparkFun 6DOF board)
// ALT high = 0x1D
ADXL345 accel;

uint16_t accArray[ACC_AVG_NUM];
uint16_t acc_avg_timeold;
uint16_t acc_avg_timenew;
float acc_avg;

void setup()
{
  // Initialize serial communication
  Serial.begin(115200);

  Serial.println(F("FLAMINGO REV B 2022"));
  Serial.println(F("by Paul Blackburn"));
  Serial.println(F("paulwb@gmail.com"));
  Serial.println(F(
      "If you find this please let me know—it means it has been stolen. Thank "
      "you!"));
  Serial.println(F(""));
  Serial.println(F(""));

  Serial.print(F("Free SRAM:  "));
  Serial.println(freeRam());
  Serial.println(F(""));

  //////////////////////// BUTTONS /////////////////
  pinMode(BUTTON1, INPUT);
  pinMode(BUTTON2, INPUT);

  //////////////////////// ADXL345 //////////////////////
  // join I2C bus (I2Cdev library doesn't do this automatically)
  Wire.begin();

  // Initialize accel
  Serial.print(F("Initializing ADXL345... "));
  accel.initialize();
  Serial.println(F("Done."));

  // Verify connection
  Serial.print(F("Testing ADXL345 connections..."));
  if (accel.testConnection())
    {
      Serial.println(F("\tADXL345 connection successful."));
    }
  else
    {
      Serial.println(F("\tADXL345 connection failed."));
    }
  Serial.println("");

  // Set Y offset
  Serial.print(F("Setting offset... "));
  accel.setOffsetY(0);
  Serial.println("Done.");

  // Set accel range
  Serial.print(F("Setting accel range to 2... "));
  accel.setRange(2);
  Serial.println(F("Done."));

  // Measure 1 second of accelerometer values and averages to create offset.
  Serial.print(
      F("Measuring 1 second of accelerometer values for zero value... "));
  initAccelOffset();
  Serial.println(F("Done."));
  Serial.println(F(""));

  // Initialize lights
  Serial.print(F("Initializing lights... "));
  FastLED.addLeds<APA102, DATA_PIN, CLOCK_PIN, COLOR_ORDER>(leds, NUMPIXELS)
      .setCorrection(CORRECTION);

  FastLED.setBrightness(brightness[0]);
  FastLED.clear();
  FastLED.show();
  Serial.println(F("Done."));

  Serial.println(F(""));
  Serial.println(F("Starting loop."));
  Serial.println(F(""));

  Serial.print(F("Free SRAM:  "));
  Serial.println(freeRam());

  timer = millis();
}

//////////////////////// LOOP ///////////////////////////////////////////////

void loop()
{
  counter++;    // do not reset, let it roll over!
  counter16++;  // do not reset, let it roll over!
  if (counter % 10 == 0)
    {
      counter_every_10_8++;
    }
  // Buttons
  checkButton1();
  checkButton2();

  /////////////// DHO GROUP    ///////////////////////////////

  //// Damped harmonic oscillator (single pixel).
  if (programIndex == 1)
    {
      setFullBrightnessOn10();

      DHO_SinglePixel();
    }

  if (programIndex == 2)
    {
      DHO_Fade();
    }

  //// Damped harmonic oscillator (blob).
  if (programIndex == 3)
    {
      DHO_Blob();
    }

  //// Damped harmonic oscillator (rainbow).
  if (programIndex == 4)
    {
      DHO_Rainbow();
    }

  //////////// BOUNCING BALL GROUP ///////////////////////////////

  if (programIndex == 5)
    {
      setFullBrightnessOn10();
      // no fade
      Bouncing_Balls(0);
    }

  if (programIndex == 6)
    {
      setFullBrightnessOn10();
      // fade
      Bouncing_Balls(1);
    }

  /////////////////// FIRE GROUP  ///////////////////////////////

  //// Green fire
  if (programIndex == 7)
    {
      // Added yellow sparks.
      GreenFireOriginal();
    }

  if (programIndex == 8)
    {
      // pink fire
      CRGBPalette16 firepal, sparkpal;
      firepal =
          CRGBPalette16(CRGB(0, 0, 0),
                        CRGB(scale8(96, 100), scale8(16, 100), scale8(40, 100)),
                        scale8(CRGB(96, 16, 40), 255), CRGB(255, 255, 255));
      CRGB sparkcolor = CHSV(230, 71, 200);
      Fire2012WithPalette(firepal, sparkcolor, 1, 0);
    }

  if (programIndex == 9)
    {
      // rainbow fire
      CRGBPalette16 firepal, sparkpal;
      firepal = RainbowColors_p;
      CRGB sparkcolor = CRGB(255, 255, 255);
      bool rotate = 1;
      Fire2012WithPalette(firepal, sparkcolor, 0, rotate);
    }

  if (programIndex == 10)
    {
      Fire2012RainbowRotate();
    }

  ///////////////////   SPARKLE GROUP ///////////////////

  //// Sparkle White
  if (programIndex == 11)
    {
      setFullBrightnessOn10();

      Sparkle(CRGB(255, 255, 255), 10);
    }

  //// Sparkle Pink
  if (programIndex == 12)
    {
      setFullBrightnessOn10();

      Sparkle(color, 10);
    }

  //// Sparkle Pink Fizz
  if (programIndex == 13)
    {
      setFullBrightnessOn10();

      SparkleFizz(color, 10);
    }

  ///////////////////  RAINBOW NON-ACC ///////////////////

  //// Rainbow(rainbow).
  if (programIndex == 14)
    {
      Rainbow_FastLED();
    }

  ////
  //  if (programIndex == 15)
  //  {
  //    Test();
  //  }
}

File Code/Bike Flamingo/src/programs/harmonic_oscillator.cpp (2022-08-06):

#include <harmonic_oscillator.h>
#include <parameters.h>
#include <programs-common.h>

#if BOARD_TYPE == 3

float pos0, pos1, vel0, vel1, acc0, acc1, acc_ext;

uint16_t timeold_i = 0;
uint16_t timenow_i = 0;
float timenow_f = 0.0;
float timestep_f = 0.0;
float timestep_i =
    0;  // check how this is used, name suggests int but decl is float

bool first_iter = 0;
uint16_t sendTime = 0;  // currently in a commented out section

//////// DAMPED HARMONIC OSCILLATOR FUNCTIONS ///////////////

float eval_v_func_DHO(float v, float x, float acc_ext, float damping,
                      float springconstant, float mass)
{
  // acc_ext is generally negative when Flamingo is upright.
  // m x'' = - k x - c v + F_ext
  // with F_ext = m acc_ext
  return -damping * v - springconstant * x + mass * acc_ext;
}

// Integrates acceleration to get velocity for DHO
float get_next_v_DHO(float oldv, float oldx, float acc_ext, float damping,
                     float springconstant, float mass)
{
  float k1, k2, k3, k4;
  k1 = eval_v_func_DHO(oldv, oldx, acc_ext, damping, springconstant, mass);
  k2 = eval_v_func_DHO(oldv + 0.5 * k1, oldx, acc_ext, damping, springconstant,
                       mass);
  k3 = eval_v_func_DHO(oldv + 0.5 * k2, oldx, acc_ext, damping, springconstant,
                       mass);
  k4 = eval_v_func_DHO(oldv + k3, oldx, acc_ext, damping, springconstant, mass);
  return (float)(oldv + timestep_f * ((k1 / 6.0) + (k2 / 3.0) + (k3 / 3.0) +
                                      (k4 / 6.0)));
}

// integrates velocity to get position
float get_next_x_DHO(float oldv, float oldx)
{
  return (float)(oldx + timestep_f * oldv);
}

int ballToStrandPosition_DHO(float ballPos_DHO)
{
  return (NUMPERSTRAND / 2) + ballPos_DHO * (NUMPERSTRAND / 2);
};

// DAMPED HARMONIC OSCILLATOR, real physical units. Returns object position as a
// float, centered on 0, so maxrange is half the length of the strip.  Resting
// location is at 0.0
float getBallPosition_DHO(void)
{
  if (first_iter == 1)  // first iteration
    {
      pos0 = 0.0;
      vel0 = 0.0;
      timenow_i = 0;
      timestep_i = timenow_i - timeold_i;
      timeold_i = millis();  // why is this timeold and not timenow? I moved
                             // this from below btw
      timestep_f = 0.01 * ((float)timestep_i);

      // getNormalizedAccelY() is negative when Flamingo is upright.
      // getNormalizedAccelY() returns normalized acc in units of g
      // Right side up: 1.0
      // Upside Down:   -1.0
      acc_ext = G_ACC_MAGNITUDE * getNormalizedAccelY();
      vel1 = get_next_v_DHO(vel0, pos0, acc_ext, DAMPING_REAL,
                            SPRINGCONSTANT_REAL, MASS_REAL);
      pos1 = get_next_x_DHO(vel0, pos0);

      timeold_i = timenow_i;
      pos0 = pos1;
      vel0 = vel1;

      first_iter = 0;
    }
  else
    {
      timenow_i = millis();
      timestep_i = timenow_i - timeold_i;
      timestep_f = 0.01 * ((float)timestep_i);

      // acc_ext is generally negative because getNormalizedAccelY() returns
      // negative when Flamingo is upright.
      // G_ACC_MAGNITUDE is positive.
      acc_ext = G_ACC_MAGNITUDE * getNormalizedAccelY();
      vel1 = get_next_v_DHO(vel0, pos0, acc_ext, DAMPING_REAL,
                            SPRINGCONSTANT_REAL, MASS_REAL);
      pos1 = get_next_x_DHO(vel0, pos0);
      vel0 = vel1;
      pos0 = pos1;
      timeold_i = timenow_i;

      /*
            uint16_t timet = millis();
            if (timet - sendTime > 100)
              {
                Serial.print(F("Time:\t"));
                Serial.print(timet);
                Serial.print(F("\tpos1:\t"));
                Serial.print((pos1));
                Serial.print(F("\tBallPosition:\t"));
                Serial.print(
                    (pos1 / (MASS_REAL * G_ACC_MAGNITUDE / SPRINGCONSTANT_REAL))
         + 1.0); Serial.print(F("\tPixel Index:\t"));
                Serial.print(ballToStrandPosition(
                    (pos1 / (MASS_REAL * G_ACC_MAGNITUDE / SPRINGCONSTANT_REAL))
         + 1.0)); Serial.print(F("\tgetNormalizedAccelY:\t"));
                Serial.print(getNormalizedAccelY());
                Serial.print(F("\tgetNormalizedOffsetAccelY:\t"));
                Serial.println(getNormalizedOffsetAccelY());
                sendTime = timet;
              }
      */
    }
  // Resting location is at 0.0
  float temp =
      (pos1 / (MASS_REAL * G_ACC_MAGNITUDE / SPRINGCONSTANT_REAL)) + 1.0;

  return temp;
}

// 1
//////////// DHO SINGLE PIXEL
////////////////////////////////////////////////////////////////////////////////////////

void DHO_SinglePixel()
{
  if (firstRun)
    {
      FastLED.clear();
      firstRun = 0;
      Serial.println(F("Starting Program:\tDHO_SinglePixel"));
      Serial.print(F("Free SRAM:  "));
      Serial.println(freeRam());
    }

  float BallPosition = getBallPosition_DHO();

  FastLED.clear();

  setPixelByStrandIndex(ballToStrandPosition_DHO(BallPosition), color);
  /*  Serial.print("\tBallPosiition:\t");
    Serial.print(BallPosition);
    Serial.print("\tPixel Index:\t");
    Serial.println(temp);
    */
  FastLED.show();
}

// 2
//////////// DHO Blob
////////////////////////////////////////////////////////////////////////////////////////

// For DHO_Blob
const uint8_t gaussianTable[19] PROGMEM = {0,   5,   12,  27,  53,  94,  145,
                                           199, 240, 255, 240, 199, 145, 94,
                                           53,  27,  12,  5,   0};

void DHO_Blob(void)
{
  if (firstRun)
    {
      FastLED.clear();
      firstRun = 0;
      Serial.println(F("Starting Program:\tDHO_Blob"));
      Serial.print(F("Free SRAM:  "));
      Serial.println(freeRam());
    }
  float BallPosition = getBallPosition_DHO();

  FastLED.clear();
  int centerindex = (uint16_t((float)NUMPERSTRAND / 2.0) +
                     BallPosition * ((float)NUMPERSTRAND / 2.0));
  float attnFactor;

  for (int k = -9; k <= 9; k++)
    {
      attnFactor =
          (uint8_t)((uint8_t)pgm_read_byte_near(gaussianTable + k + 9));
      /*    Serial.print("attnFactor: ");
          Serial.println(attnFactor);
                Serial.print("k: ");
          Serial.println(k);*/

      setPixelByStrandIndex(centerindex + k, scale8(color.r, attnFactor),
                            scale8(color.g, attnFactor),
                            scale8(color.b, attnFactor));
    }
  FastLED.show();
}
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

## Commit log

2017-05-06 Move variables to PP defs, debug crashing
    Tidied up code, started addressing why the board built for BM 2016
    crashes. Added freeRAM() to diagnose. Consistently crashes when it
    reaches DHO_Sinetripes(). At that point free SRAM is around 147, and
    then I try to load a huge float table.
    Committing before trying to reduce the memory requirements of this
    program.
    [accel.cpp, buttons.cpp, main.cpp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]
2017-05-06 Putting big things in PROGMEM
    Found why it was crashing. Free SRAM was 147 before moving a huge float
    table to PROGMEM and changing floats to ints (later dividing by 100.0),
    plus another PROGMEM change. I also put all setup() Serial strings in
    F().
    After all these changes, free SRAM is at 927!
    [main.cpp, parameters.h]
2017-05-07 A few more PP refs and F()
    Moved a few more variables to PP defs and strings into F().
    Open issue: the blob program’s values follow the blob shape but
    flicker, therefore the array is not being read correctly from PROGMEM.
    [accel.cpp, main.cpp, parameters.h]
2017-05-07 Fixed issue with flickering DHO_Blob
    I forgot to use the PROGMEM accessing function.
    Open issue: there seem to be 3 unused LEDs.
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2017-05-09 Trying to understand behavior of SparkleFizz
    SparkleFizz does not change gracefully from short to long random
    intervals. The issue seems to be with random(0, MAX) giving only 0 and
    MAX and nothing in between.
    [main.cpp, parameters.h]
2017-05-10 Continued work on Sparkle Fizz
    The issue is that for max acceleration greater than MAX_G_SPARKLEFIZZ,
    it takes a while for acc_decayed to be equal to MAX_G_SPARKLEFIZZ. If
    acc_max is twice MAX_G_SPARKLEFIZZ, half of ACC_MAX_DECAY_RATE is spent
    at solid sparkle, leaving only the other half to get down to zero (for
    a linear decay).
    What’s needed is a separate decay timescale that starts at that moment,
    maybe using an if statement to choose how acc_decayed is calculated:
    linear at first, then when acc_decayed is below MAX_G_SPARKLEFIZZ, take
    a new t0 and decay according to this new decay rate.
    This decay should probably be exponential but slow. A sigmoid might
    work well too.
    [parameters.h]
2017-05-11 First acceptable SparkleFizz
    Damn, that was hard. Eventually settled for:
    * If acc_max is bigger than MAX_G_SPARKLEFIZZ, set acc_max to
    MAX_G_SPARKLEFIZZ. Also:
    if (acc_now >= MAX_G_SPARKLEFIZZ)
    {
    acc_now = MAX_G_SPARKLEFIZZ;
    //Force sparkle for a hard jerk
    sparkleInterval = 0;
    }
    Note that I stuck the sparkleInterval reset on acc_max >
    MAX_G_SPARKLEFIZZ, and not any time acc_now > acc_max. The latter made
    resting acc values trigger max sparkle constantly.
    * Decay acc_max with acc_decayed using a linear, not exponential
    function.
    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
    [main.cpp, parameters.h]
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2017-05-12 Changed SparkleFizz rate to 20 seconds
    Looks better.
    At this point I’d say this program is “good enough”. The derivative of
    acceleration will have to wait. I’m not convinced it will be much of an
    improvement. Picking a derivative interval doesn’t seem
    straightforward.
    On to new programs.
    [parameters.h]
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2017-05-13 Fixed accel functions: now really physical
    Found I had used acc_now instead of m*a in the integration of the
    equation of motion.
    getBallPosition() now returns 0 when upright and -2.0 when inverted, no
    matter what parameters are chosen for m, k and c.
    Parameters might need a little tweaking.
    [accel.cpp, harmonic_oscillator.cpp, main.cpp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]
2017-05-15 Worked on DHO Fade and Comet; added utils.cpp/h
    Both DHO Fade and Comet are unsatisfactory. Fade has gaps when the ball
    moves too fast to register on all pixels, and Comet doesn’t seem to
    display the trail, no matter how long I make the history.
    Added utils.cpp/h for stuff like freeRam().
    Renamed setPixelByIndex to setPixelByStrandIndex for clarity.
    Added fadeWholeStrip(float fade_coef) and void
    getPixelColorAsArray(index, uint8_t* pixel).
    [harmonic_oscillator.cpp, main.cpp, parameters.h]
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2017-05-22 FastLED transition cleanup
    The standard Flamingo Pink color is too blue.
    The green fire looks too blue too.
    DHO_Blob seems to be asymmetrical, being truncated on the higher index
    side.
    DHO_Fade now looks great, no gaps, about 2-3 ms per program cycle.
    DHO_Comet is too slow still.
    [buttons.cpp, main.cpp, parameters.h]
2017-05-22 FastLED transition cleanup continues
    My LED color order was wrong, so Flamingo pink looked too blue. Now
    things are as they should be. DHO_Comet is not working but I’m not too
    tied to it anyway. Can probably be fixed easily.
    [parameters.h]
2017-05-23 Created programs/ dir
    effects.cpp was getting too long. Created programs-common.h and .cpp
    Transition to FastLED() is complete, save for some tweaks and
    adaptation.
    [fire.cpp, harmonic_oscillator.cpp, main.cpp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]
2017-05-23 Corrected COLOR_ORDER, added Fire With Palette
    Used RGBCalibrate example to finally figure out what the order should
    be. Amazing I could get it wrong a few times and still have the colors
    I wanted. I guess all of Flamingo was pink, which kinda worked, then
    green, which was wrong in the first place, and rainbows. And white. Wow.
    [fire.cpp, main.cpp, parameters.h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]
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2017-05-24 Added Bouncing Balls. Totally does not work.
    [bouncing_balls.cpp, harmonic_oscillator.cpp, main.cpp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]
2017-05-24 Bouncing balls still not working
    Each ball is slower than the next. Need to check how timing intervals
    for RK are set.
    [bouncing_balls.cpp, parameters.h]
2017-05-24 BB issue potentially fixed
    The first ball would see a time interval roughly equivalent to the cycle
    time for BB(), whereas the subsequent ones saw essentially the
    inter-ball interval. Fixed so each ball struct now carries its own
    record of the last time it was updated. With this I hope the balls will
    behave properly.
    [bouncing_balls.cpp, harmonic_oscillator.cpp, parameters.h]
2017-05-25 Added rainbow.cpp; pre-release for LIB2017
    Changed to FastLED’s rainbow functions. Used them in DHO Rainbow.
    Kept original fire because it has more yellow than a rgb -> grb swapped
    pallette fire. Added sparks to it. Added pink fire. Added rainbow fire.
    OMG.
    [fire.cpp, harmonic_oscillator.cpp, main.cpp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]
2017-05-25 Small fixes for Totem
    Totem’s accelerometer is upside down. That explains A LOT.
    [accel.cpp, parameters.h, rainbow.cpp]
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2017-07-27 Added reference files
    Added reference files for the JST SM connectors, Pro Trinket and so on.
    [Adafruit MicroLipo.brd, Adafruit MicroLipo.sch, Adafruit MicroUSB Lipo.brd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]
2017-07-27 Added components to schematic
    Nothing connected to nets yet.
    [Adafruit MicroLipo.brd, Adafruit MicroLipo.sch, Adafruit MicroUSB Lipo.brd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]
2017-07-29 Completed preliminary component layout
    Decided to just glue the 5 wires from the remote and 4 for the lights
    to the underside of the PCB.
    [Flamingo PCB Rev 1.1.brd, Flamingo PCB Rev 1.1.sch]
2017-12-17 Switch to KiCad
    Given that Eagle is garbage, I am switching to KiCad.
    [Flamingo PCB.kicad_pcb, Flamingo PCB.sch]
2018-02-05 Starting to create Rev 2
    [Adafruit MicroLipo.brd, Adafruit MicroLipo.sch, Adafruit MicroUSB Lipo.brd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]
2018-02-06 First pass of battery charging section complete
    Still needs another pass for component and value selection.
    [Flamingo_PCB.sch]
2020-09-30 Fixing a mess
    [Adafruit MicroLipo.brd, Adafruit MicroLipo.sch, Adafruit MicroUSB Lipo.brd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]
2020-10-03 Adding first sub-sheets
    Arduino
    Battery Charger
    IMU
    Power
    [Flamingo PCB - Arduinosch.sch, Flamingo PCB - Battery Charger.sch, Flamingo PCB - IMU.sch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]
2020-10-07 PCB: bringing in symbols, re-making battery charger sheet, still has todo
    [Flamingo PCB - Arduinosch.sch, Flamingo PCB - Battery Charger.sch, Flamingo PCB - Battery Chargerzzzzz.sch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]
2020-10-08 Advanced schematic for battery charger
    To do:
    * Find a better connector for the switch than a JST PH2
    * Check the polarity of the battery connector w.r.t. Adafruit batteries.
    *Assign footprints
    [Flamingo PCB - Arduinosch.sch, Flamingo PCB - Battery Charger.sch]
2020-10-08 Fixed footprint libraries to v5, added some footprints
    [Flamingo PCB - Battery Charger.sch, Flamingo PCB.kicad_pcb]
2020-10-09 Changed ATMEGA328P for a modified DK symbol
    [Flamingo PCB - Battery Charger.sch, Flamingo PCB.sch]
2020-10-09 Worked on Power board mainly.
    Still have to resolve the power sharing.
    [Flamingo PCB - Arduinosch.sch, Flamingo PCB - Battery Charger.sch, Flamingo PCB - Power.sch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]
2020-10-10 NOSTUFF 5V LDO bc not needed. Added Sch diode on 5v LDO.
    [Flamingo PCB - Arduinosch.sch, Flamingo PCB - Battery Charger.sch, Flamingo PCB - Power.sch]
2020-10-12 Moved Battery Charger sheet into Power sheet
    Right before addition of power sharing mosfet, maybe
    [Flamingo PCB - Battery Charger.sch, Flamingo PCB - Power.sch]
2020-10-12 Tidied up Power schematic, trying for load switching P-channel MOSFET
    [Flamingo PCB - Arduinosch.sch, Flamingo PCB - IMU.sch, Flamingo PCB - Power.sch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]
2020-10-13 More work on Arduino schematic, created button board schematic
    Button board schematic should probably be a separate project
    [Flamingo PCB - Arduinosch.sch, Flamingo PCB - Button Remote.sch, Flamingo PCB - IMU.sch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]
2020-10-13 More work on Arduino sheet
    Added V_BUS sensing, removed V_BAT sensing bc it would be a discharge situation. Assigned some lines to pins. Added placeholders for headers.
    [Flamingo PCB - Arduinosch.sch, Flamingo PCB - Power.sch]
2020-10-13 Tidy up
    [Flamingo PCB - Arduinosch.sch, Flamingo PCB - Button Remote.sch, Flamingo PCB - IMU.sch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]
2020-10-14 Wired up top-level sheet, fixed some hier. pins
    [Flamingo PCB - Arduinosch.sch, Flamingo PCB - Button Remote.sch, Flamingo PCB - IMU.sch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]
2020-10-18 Added Button Remote project
    [Button Remote for Flamingo PCB.kicad_pcb, Button Remote for Flamingo PCB.sch, Flamingo PCB - Arduinosch.sch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]
2022-05-20 Undocumented changes
    [Flamingo PCB - Power.sch, Flamingo PCB.sch]
2022-05-20 Created through hole files, did not do anything
    [Flamingo Through Hole Project.kicad_pcb, Flamingo Through Hole Project.kicad_sch]
2022-05-25 Fixed compilation issue by copying I2Cdevlib files into lib/ and discovered rewrite is very incomplete womp womp
    https://community.platformio.org/t/library-header-not-found-installed-library-seems-to-be-empty/27841/5
    [bouncing_balls.cpp, harmonic_oscillator.cpp, parameters.h]
2022-05-25 It finally builds. Turns out going with main branch instead of dev was a bad idea. Or something
    Fixed it by copy pasting in code that seems to have been accidentally nuked, harmonic_oscillator.cpp.
    [harmonic_oscillator.cpp, main.cpp]
2022-08-01 Re-adding Bike Flamingo after wiping repository due to broken stash
    [main.cpp]
2022-08-01 Fixed button debounce, now can fast press
    [main.cpp]
2022-08-02 Started creating carrier board schematic for Bike Flamingo
    [Bike Flamingo for Itsy Bitsy 5V 16MHz, USB Power Rev 1.kicad_pcb, Bike Flamingo for Itsy Bitsy 5V 16MHz, USB Power Rev 1.kicad_sch]
2022-08-02 Finished Bike Flamingo board Rev 1
    [Bike Flamingo for Itsy Bitsy 5V 16MHz, USB Power Rev 1.csv, Bike Flamingo for Itsy Bitsy 5V 16MHz, USB Power Rev 1.kicad_pcb]
2022-08-03 As ordered from JCLPCB with generated gerbers
    [Bike Flamingo for Itsy Bitsy 5V 16MHz, USB Power Rev 1-B_Cu.gbl, Bike Flamingo for Itsy Bitsy 5V 16MHz, USB Power Rev 1-B_Mask.gbs, Bike Flamingo for Itsy Bits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]
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2022-08-03 Finally got brightness array to pass compile
    [77136050.xlsx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]
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2022-08-03 Found the memory corruption location, will have to adapt to arbitrary number of strands
    The issue is here
    void setPixelByStrandIndex(uint16_t index, CRGB color)
    if ((index >= 0) && (index < NUMPERSTRAND))
    // index goes from 0 to NUMPERSTRAND - 1
    uint8_t realindex = 0;
    // NUMPERSTRAND - 1
    // 0
    realindex = NUMPERSTRAND - index - 1;
    leds[realindex] = color;
    // NUMPERSTRAND
    // 2*NUMPERSTRAND - 1
    realindex = NUMPERSTRAND + index;
    leds[realindex] = color;
    // 3*NUMPERSTRAND - 1
    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
    [buttons.cpp, fire.cpp, main.cpp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]
2022-08-03 Fixed the bug with the memory corruption, commented out a lot of print statements
    [fire.cpp, main.cpp, parameters.h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]
2022-08-04 Added some notes on power: the battery connector is not likely to be useful
    Since if USB is unplugged, the only route to the LED VCC (VBUS) is through the 5 V regulator. This is also true if a battery backpack is used.
    Does it make sense to put the batt connector on the VUSB line? Not really, because then the Arduino just sees unregulated batt... which is OK for a LiPo I guess.
    Does it make sense to change the LEDs to use VBAT? With VBAT and no USB present, the LEDS get direct battery and the arduino gets regulated output. With USB and no VBAT the LEDs dont see VBUS unless 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
    [Bike Flamingo for Itsy Bitsy 5V 16MHz, USB Power Rev 1.kicad_sch]
2022-08-06 Preprocessor commenitng out for board type
    [Bike Flamingo for Itsy Bitsy 5V 16MHz, USB Power Rev 1.kicad_sch]
2022-08-11 Found issues with Rev 1 Bike Flamingo, made Rev 2, added time()
    [77136050.xlsx, Bike Flamingo for Itsy Bitsy 5V 16MHz, USB Power Rev 2.csv, Bike Flamingo for Itsy Bitsy 5V 16MHz, USB Power Rev 2.kicad_pcb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]
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2023-04-28 Carrier board for Arduino Nano 33 BLE Rev 2 sent to fab
    [Adafruit FET 4-Channel Shifter.brd, Adafruit FET 4-Channel Shifter.sch, Adafruit Pro Trinket 3v3.brd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]
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2023-05-04 Damped Harmonic Oscillator is working
    Found good settings for 120 BPM bounce. Also fixed the ball being waaaay far out when it is first run, caused by the timing interval not being updated during setup()
    [harmonic_oscillator.cpp, imu.cpp, main.cpp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]
2023-05-07 A little more advancement on harmonic oscillator, beginnings of a program structure, etc
    [buttons.cpp, harmonic_oscillator.cpp, main.cpp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]
2023-05-08 Removed while(!Serial), prevented loop start until connected to apparently
    [harmonic_oscillator.cpp, imu.cpp, main.cpp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]
2023-05-09 Fixed first_run, made bounce more or less adequate.
    [bouncing_ball.cpp, harmonic_oscillator.cpp, imu.cpp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]
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2023-05-25 measured two batteries on max burn with this code
    [main.cpp]

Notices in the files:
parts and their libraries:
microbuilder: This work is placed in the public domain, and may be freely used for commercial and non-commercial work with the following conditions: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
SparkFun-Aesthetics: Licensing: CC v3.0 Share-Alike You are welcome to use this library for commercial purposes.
